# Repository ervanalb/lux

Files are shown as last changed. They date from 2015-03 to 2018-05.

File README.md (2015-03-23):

lux
===

Lux is a protocol for the transmission of power and data from a host device to one or more nodes. It is capable of data rates approaching 3 megabits per second and supplying 30 Watts of power over distances of up to 100 feet. It is designed to be easy to implement and uses low-cost cabling and connectors.

Lux was designed as a lighting control protocol, specifically for LED strips. But, it generalizes nicely to any sort of automation on a small to medium scale.

For tech-specs of the protocol, see SPECS.md.

In this repository, you will find:

Library
-------

The lux library is a architecture-independent implementation of the lux in C which you can use to implement your own lux nodes. Simply provide the necessary simple hardware abstraction layer, and you're good to go. The implementation fits in under 8K of program memory and 2K of RAM (1K of which is shared with the application) on a Cortex-M0.

LED strip firmware
------------------

This is a real-world instantiation of the lux protocol to control WS2811 or LPD6803 light strips. It uses a STM32F030 at 48 MHz, which has only 32K of FLASH and 4K of RAM for all of the processing. The code also implements a bootloader for firmware upgrades over lux.

Python
------

There is also a python implementation of a lux master using pyserial.

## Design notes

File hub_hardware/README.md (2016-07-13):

Lux Hub Hardware
================

History
-------

### Rev 6

#### Errata

- 

##### Bad parts

- U3
- R42
- C3 is short
- Fuse clips
- CON1 holes should be bigger

### Rev 5

- STM32F042
- 6 Lux outputs
    - 48V power, 5V/0V RS-422 data
    - Data lines tied together
    - Rx/Tx enable are indepedent
    - TVS on data lines
    - Per-output PTC fuses (which weren't useful)
- USB for comms & non-48V power
    - Spec'd for 500mA current draw to drive 6 ports
- *Greenwire*: 3v3 reg `U1` pads are incorrect
- *Greenwire*: Inrush limiter changed: `R42 -> C; C1 -> R; R1` unpopulated
- *Greenwire*: RX pin incorrect; shorted to TX LED

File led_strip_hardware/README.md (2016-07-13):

LED Strip Hardware
==================

Unified (v5, v6, v7)
------------

v7 Changelog
------------
- Doubled `C1` with `C10` (`+48V` filtering)
- Doubled `C9` with `C11` (`3V3` filtering)
- Added `C12`, 100nF decoupling cap to `U3`
- Improved DFM

v6 Changelog
------------
(Minor revision)
- Added soft-start circuit (`Q1`, `R9`, `R10`) to `+48V`
- Added bias resistors (`R11`, `R12`) to RS-422 lines
- Added transient voltage suppressor (`U5`) to RS-422 lines
- "*Greenwire*": Doubled `C1` (`+48V` filtering)
- "*Greenwire*": Doubled `C9` (`3V3` filtering)
- "*Greenwire*": Added 2x 100nF decoupling caps to `U3`

History
-------

### Rev 5-7

- 2015-2016
- STM32-based
- Comms: RS-422 half-duplex (actually works now)
    - Hub for multiplexing, but not a router
    - Network (UDP) bridge
- Power: 48V + buck
- Rendering: Control-side, full frames sent
- Control: Radiance: https://github.com/zbanks/radiance
    - Visual UI written in C & SDL
    - Effects on a 2D plane, rendered onto strips
    - Tight audio integration & visualization
        - Beat tracking: https://github.com/zbanks/BTrack

### Rev 3-4???

- 2014
- STM32-based
- Comms: RS-422 half-duplex
    - Non-simplex was incredibly unreliable
    - Full router prototyped, never worked
- Power: 48V + buck
- Rendering: Control-side, full frames sent
    - (Bespeckle used intermittently? Unclear)
- Control: Numerous revisions
    - Livecoding python: https://github.com/zbanks/beetle
        - Visual UI with grassroots: https://github.com/zbanks/grassroots
        - #doitlive: https://github.com/zbanks/doitlive
        - Effects projected on a 2D plane and rendered for strips
        - Used audio information (but not well), beats manually sync'd (?)
    - Beat-off: https://github.com/ervanalb/beat-off/tree/python-1d
        - Visual UI
        - 1D LED strips with effects composited
        - Audio info displayed, beats manually sync'd, effects use timing
- Repo: https://github.com/zbanks/aurora

### Rev 2

- Aug 2013
- STM32-based
- Comms: CAN
    - Bastardization of the protocol to get multicast
    - Possibly send-only?
- Power: 48V + buck
- Rendering: Bespeckle, rendering computed on-board
    - https://github.com/zbanks/bespeckle
- Control: Cursedlight, many-keyboards + TUI
    - https://github.com/zbanks/cursedlight
    - Audio manually sync'd
- Repo: https://github.com/ervanalb/canautomation

### Rev 1

- Aug 2012
- CPU: AVR("arduino compatible"!)
- Comms: MIDI
- Power: 12V DC jack
- Rendering: effects computed on board
    - Each MIDI note corresponded to effect + color
- Control: seq24 used for control
    - MIDI clock sync'd from Mixxx

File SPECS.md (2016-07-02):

Lux Specification
=================

Lux refers to a protocol stack which is designed to control many lightweight nodes. 

It supports the transmission of power and data from a host device to one or more nodes over a simple serial link. This mode is capable of data rates approaching 3 megabits per second and supplying 30 Watts of power over distances of up to 100 feet. It is designed to be easy to implement and uses low-cost cabling and connectors.

Additionally, it also supports transmitting data over UDP (e.g. with IP & Ethernet). This mode makes it easy to abstract the controller from the physical hardware.

### Stack Comparison

The *Serial/Hardware* stack is:

1. Serial Physical Layer (48V; RS-485; 3Mbps)
2. Data Link Layer (COBS; CRC)
3. MAC Layer (Speak-when-spoken-to)
4. Application Layer

The *Network/IP* stack is:

1. Physical Layer (Unspecified; e.g. Ethernet)
2. Data Link Layer (Unspecified; e.g. IPv4)
3. Transport Layer (UDP)
3. Data Link Layer (COBS; CRC)
3. MAC Layer (Speak-when-spoken-to)
4. Application Layer

Serial Physical Layer
---------------------

Lux is designed with a hub-and-spoke model in mind. Each lux universe must have exactly one master but may have an arbitrary number of nodes (limited only by the bandwidth of the bus.)

The master exposes one or more RJ-11 jacks (6p4c) and each node exposes one RJ-11 jack. Devices are connected with straight-through RJ-11 cables no longer than 100 feet and no thinner than 26 AWG per conductor.

The lux pinout is as follows:
 1. GND
 2. A
 3. B
 4. PWR

The voltage that nodes see between PWR and GND is nominally 48 volts, but may be as high as 54 volts or as low as 42 volts. The master or hub provides this power, and nodes consume it. The master should not output less than 48 volts or more than 54 volts. The drop in the cabling may be as large as 6 volts.

Nodes may be bus-powered or self-powered. A bus-powered node must not draw more than 650 mA from the bus. A self-powered node must use GND as reference for the data signals (i.e. must not be floating or at a different potential from the bus.)

RS-485 is used for the data lines. Nodes and masters should implement the recommended bias resistors and a termination resistor of 120 ohms, as well as a RS-485 compatible tranceiver capable of 3 megabit per second communcation. The serial protocol uses 3 megabaud, 8 data bits, 1 start bit, 1 stop bit, and no parity. The serial link is half-duplex.

Network Transport Layer
-----------------------

Lux uses UDP for sending data over the Internet/LAN. Lux does not specify which protocols must be used below UDP, but usualy it is IPv4 or IPv6.

Common Layers
-------------
### Data Link Layer
Lux packets are encoded using consistent-overhead byte stuffing (COBS). A NULL (out-of-band 0 byte) is placed at the end of a packet. 

Multi-byte values are transmitted in little-endian format (*not* "network"/big-endian!)

A packet consists of five parts:

<table><tr>
 <td>Destination Address <br> (4&nbsp;bytes)</td>
 <td>Command <br> (1&nbsp;byte)</td>
 <td>Index <br> (1&nbsp;byte)</td>
 <td width="100%">Payload <br> (0-1024&nbsp;bytes) </td>
 <td>CRC <br> (4&nbsp;bytes) </td>
</tr></table>

The destination address is four bytes. Nodes may have one or more addresses. One address may be used by multiple nodes (useful for multicast.) Because lux uses hubs, all traffic generated by the host will reach every node. Nodes should filter packets based on the address, and discard any packets not addressed to them. For the rest of this document, the address is assumed to be little-endian.

The *command* and *index* fields are one byte each. They are used by the application layer.

The payload can be between 0 and 1024 bytes long, inclusive (after COBS decoding.) The data contained in the payload is not specified by lux, except by way of the defacto standards described below. Packets with payloads longer than 1024 bytes should be discarded as corrupt.

After the payload comes a 32-bit CRC of the entire packet (after COBS decoding.) If the CRC does not check out, the packet should be discarded as corrupt.

Payload length is never explicitly stated. Instead, packets are null-teriminated. Payload length is defined as the packet length minus 8 bytes, to account for the address and checksum.

Packets shorter than 8 bytes should be discarded, though not necessarily marked as corrupt. An optional feature of this protocol is to start (as well as end) packets with a null. When this happens, the decoder may interpret the data between packets as packets. On an ideal busimplementing this two-zero variant, these packets are of length 0 and do not indicate an error condition.

### MAC Layer

Lux uses a speak-when-spoken-to access control scheme. The master sends packets out to the nodes, and may optionally expect a response. If the master expects a response and does not receive one, it may re-send the packet after a timeout mutually agreed upon in advance by the node and the master. Nodes can only send data back to the master. Node should never spuriously send packets, as they may collide with packets originating from the master.

Due to the topology of the bus, packets originating from nodes will not necessarily reach other nodes. Nodes that are sending packets to the master should clear the destination field (set it to all zeros.) Nodes should never react to packets with this address.

### Application Layer

Each packet sent to a node is a *command*. Commands should be as idempotent/stateless as possible.

The command byte (octet 5) indicates the command type. `0x00` through `0x1F` are reserved for commands common to all lux devices, `0x20` through `0xFF` are device-specific. Example commands inclue ``GET_ID``, ``RESET``, ``GET_ADDR``, ``SET_ADDR``, ``GET_PKTCNT``, ``RESET_PKTCNT``, etc. 

<!-- Some command IDs are common to all lux nodes, others are specific to particular node types. For example, ``FRAME`` is specific to LED strips. -->

#### Responses

In keeping with the MAC, nodes can only transmit responses -- they cannot "push" data. Some commands are *send-recieve*, and are defined to require a response. Others like ``RESET`` are *send-only* do not have a response. It is a violiation of the MAC to respond to send-only command, or to respond with zero or multiple packets to a send-recieve command.

In a response, the destination is set to `0x00000000`, and the `command` and `index` fields are copied from the request packet.

A commmon response is a simple *ACK* containing no other data. In this case, the first byte of the payload is set to `0x00`, followed by the CRC from the request packet. Alternatively, in the case of an error (*NAK*), the response consists of a non-zero error code, followed by the CRC of the request packet (as in an *ACK*).

#### Command Descriptions

Name            | Resp.     | Payload           | Description 
----------------|-----------|-------------------|-------------
`RESET`         | None      | `flags`, 1 byte   | Reboot/reset the node. `flags` are implementation-specific.
`GET_ID`        | Data      | None              | Respond with string containing node name. Identifies implementation running on node.
`GET_DESCRIPTOR`| Data      | None              | Respond with JSON blob describing node.
`GET_ADDR`      | Data      | None              | 72 byte address struct, each `u32`: `{mcast_addr, mcast_mask, unicast_addrs[16]}`
`SET_ADDR`      | Ack       | `addrs`, 72 bytes | Respond with address list, see `GET_ADDR`
`WRITE_CONFIG`  | Ack       | None              | Flush configuration changes to nonvolatile storage
`GET_PKTCNT`    | Data      | None              | Respond with 20 byte counter struct, each `u32`: `{good, malformed, overrun, bad_crc, rx_interrupted}`
`RESET_PKTCNT`  | Ack       | None              | Reset all packet counters to 0

#### `index`

In some cases, it is desirable for a command to transmit more than 1024 bytes. The `index` parameter allows bulk transfers (up to 256kB) by selecting a slice of a request/response.

If a command requires multiple packets, it is important to note that there is no "transaction" -- the node is not required to maintain state. As a result a node does not need to keep track of which segements it has sent or received.

De-facto standards
------------------

The following are not mandatory for implementing a correctly-functioning lux node. However, they are highly recommended to maintain compatibility between nodes.

Nodes should always accept packets on address 0xFFFFFFFF. That way, a node with an unknown or corrupt address filter can always be reached.

Uninitialized nodes should assume address 0x80000000. That way, the master can "enumerate" new nodes by continuously sending zero-length packets to 0x80000000. When an unitialized node is found, it should be configured with a permanent address and stop listening on 0x80000000.

Lux Devices
===========

LED Strip
---------

### Description

A collection of up to 65535 RGB pixels. Each pixel can be controlled independently, with 24 bits of color depth.

### Command Descriptions

In addition to the generic lux commands:

Name            | Resp.     | Payload               | Description 
----------------|-----------|-----------------------|-------------
`FRAME`         | None      | `frame`, *3n* bytes   | Display the payload
`FRAME_ACK`     | Ack       | `frame`, *3n* bytes   | See `FRAME`, but ack
`FRAME_HOLD`    | None      | `frame`, *3n* bytes   | Buffer the payload as a frame, but don't display it
`FRAME_HOLD_ACK`| Ack       | `frame`, *3n* bytes   | See `FRAME_HOLD`, but ack
`SYNC`          | None      | None                  | Display the buffered frame from `FRAME_HOLD` or `FRAME_HOLD_ACK`
`SYNC_ACK`      | Ack       | None                  | See `SYNC`, but ack
`SET_LED`       | Ack       | None                  | Turn the on-board LED on or off
`GET_BUTTON_CNT`| Data      | None                  | Respond with number of times the button has been pressed
`SET_LENGTH`    | Ack       | None                  | Set the number of pixels
`GET_LENGTH`    | Data      | None                  | (*To be deprecated*) Respond with number of pixels

`frame` buffers must be exactly *3n* bytes long, where *n* is the length of the strip as discovered by `GET_DESCRIPTOR` or `GET_LENGTH`.
The three consecutive bytes represent `R`, `G`, and `B` components respectively. 

LED Spot
--------

### Description

A single RGB pixel with 24 bits of color depth

### Command Descriptions

In addition to the generic lux commands:

Name            | Resp.     | Payload               | Description 
----------------|-----------|-----------------------|-------------
`FRAME`         | None      | `frame`, 3 bytes      | Display the payload
`FRAME_ACK`     | Ack       | `frame`, 3 bytes      | See `FRAME`, but ack
`FRAME_HOLD`    | None      | `frame`, 3 bytes      | Buffer the payload, but don't display it
`FRAME_HOLD_ACK`| Ack       | `frame`, 3 bytes      | See `FRAME_HOLD`, but ack
`SYNC`          | None      | None                  | Display the buffered color from `FRAME_HOLD` or `FRAME_HOLD_ACK`
`SYNC_ACK`      | Ack       | None                  | See `SYNC`, but ack
`SET_LED`       | Ack       | None                  | Turn the on-board LED on or off

Bootloader
----------

### Description

A bootloader implementation for re-flashing devices in the field.

### Command Descriptions

In addition to the generic lux commands:

Name            | Resp.     | Payload               | Description 
----------------|-----------|-----------------------|-------------
`INVALIDATE_APP`| Ack       | None                  | Prevent the existing application from booting
`FLASH_ERASE`   | Ack       | `u32 addr` page       | Erase a FLASH page at base address `addr`
`FLASH_WRITE`   | Data      | `u32 addr, data[]`    | Write `data` to FLASH at address `addr`. Respond with data written.
`FLASH_READ`    | Data      | `u32 addr, u16 len`   | Read back `len` bytes of data from `addr`

It is important to call `INVALIDATE_APP` before writing to FLASH.
This "atomically" re-writes the ISR page to point to the bootlodaer, which causes subsequent reboots to jump to the bootloader instead of the application until the flashing is done.

The flashing process should go as follows: 

```
    > INVALIDATE_APP
    < Ack
    > FLASH_ERASE 0x800
    < Ack
    > FLASH_WRITE 0x800 deadbeef...
    < deadbeef...
    > FLASH_WRITE 0x900 deadbeef...
    < deadbeef...
    > FLASH_ERASE 0x400
    < Ack
    ...
    > FLASH_WRITE 0x000 deadbeef...
    < deadbeef...
    > RESET
```

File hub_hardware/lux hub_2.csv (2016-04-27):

100n | 2 | C5 C6
1u | 1 | C2
2u2 | 1 | C4
470u | 1 | C3
C | 1 | C1
C | 6 | C7 C8 C9 C10 C11 C12
48V | 1 | CON1
USB-MINI-B | 1 | CON2
TX | 1 | D1
RX | 1 | D2
ENABLED | 6 | D3 D5 D7 D9 D11 D13
PWR | 6 | D4 D6 D8 D10 D12 D14
VDD | 1 | D15
+48V | 1 | D16
5A | 1 | F1
CONN_4 | 7 | P1 P2 P3 P4 P5 P6 P7
DMP6023LE-13 | 1 | Q1
120R | 6 | R8 R14 R20 R26 R32 R38
470R | 9 | R4 R5 R6 R12 R18 R24 R30 R36 R50
680R | 12 | R7 R13 R19 R25 R31 R37 R9 R15 R21 R27 R33 R39
2K2 | 6 | R11 R17 R23 R29 R35 R41
4K7 | 1 | R2
10K | 7 | R3 R43 R44 R45 R46 R47 R48
10k | 1 | R49
R | 2 | R1 R42
PTC | 6 | R10 R16 R22 R28 R34 R40
BOOT | 1 | SW1
4068 | 1 | U3
3V3REG | 1 | U1
ISL83485IBZ | 6 | U4 U6 U8 U10 U12 U14
2CH-TVS | 6 | U5 U7 U9 U11 U13 U15
STM32F042-32 | 1 | U2

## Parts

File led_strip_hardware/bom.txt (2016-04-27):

C1:C3225X7R2A225K230AB
C6:16SVPF82M
C7:16SVPF82M
D2:STPS20M100S
P1:A-2004-0-4-LP-N-R
SW1:FSM4JSMA
U1:ISL83485IBZ
U3:STM32F030K6T6
U4:AP1117IE33G-13

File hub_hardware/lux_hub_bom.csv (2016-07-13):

Digi-Key Part Number | Manufacturer | Manufacturer Part Number | Customer Reference | Quantity 1 | Quantity 2 | Quantity 3 | Mfg Std Lead Time | Description | Comments | RoHS Status | Lead Free Status | REACH Status
490-10458-1-ND | MURATA ELECTRONICS (VA) | GRM155R62A104KE14D | C1,C13 | 2 | 0 | 0 | 16 Weeks | CAP CER 0.1UF 100V X5R 0402 | Alternate Packaging Exists | RoHS Compliant | Lead free | Unaffected Dec-2015
490-13341-1-ND | MURATA ELECTRONICS (VA) | GRM155R71E104ME14D | C5,C6,C7,C8,C9,C10,C11,C12,C13,C14 | 10 | 0 | 0 | 18 Weeks | CAP CER 0.1UF 25V X7R 0402 | Alternate Packaging Exists | RoHS Compliant | Lead free | Unaffected Dec-2015
1276-1066-1-ND | SAMSUNG ELECTRO-MECHANICS AMERICA, INC (VA) | CL21B105KAFNNNE | C2 | 1 | 0 | 0 | 10 Weeks | CAP CER 1UF 25V X7R 0805 | Alternate Packaging Exists | RoHS Compliant | Lead free | Unaffected Dec-2015
1276-2953-1-ND | SAMSUNG ELECTRO-MECHANICS AMERICA, INC (VA) | CL21B225KAFNFNE | C4 | 1 | 0 | 0 | 10 Weeks | CAP CER 2.2UF 25V X7R 0805 | Alternate Packaging Exists | RoHS Compliant | Lead free | Unaffected Dec-2015
1276-6462-1-ND | SAMSUNG ELECTRO-MECHANICS AMERICA, INC (VA) | CL21A475KAQNNNG | C15 | 1 | 0 | 0 | 10 Weeks | CAP CER 4.7UF 25V X5R 0805 | Alternate Packaging Exists | RoHS Compliant | Lead free | Not Available
160-1435-1-ND | LITE-ON INC (VA) | LTST-C190KGKT | D1,D3,D5,D7,D9,D11,D13,D15 | 8 | 0 | 0 | 10 Weeks | LED GREEN CLEAR 0603 SMD | Alternate Packaging Exists | RoHS Compliant | Lead free | Unaffected Dec-2015
160-1436-1-ND | LITE-ON INC (VA) | LTST-C190KRKT | D2,D4,D6,D8,D10,D12,D14,D16 | 8 | 0 | 0 | 10 Weeks | LED RED CLEAR 0603 SMD | Alternate Packaging Exists | RoHS Compliant | Lead free | Unaffected Dec-2015
AE10382-ND | ASSMANN WSW COMPONENTS | A-2004-0-4-LP-N-R | P1,P2,P3,P4,P5,P6 | 6 | 0 | 0 | 16 Weeks | CONN MOD JACK 6P4C R/A UNSHLD |  | RoHS Compliant | Lead free | Unaffected Dec-2015
DMP6023LE-13DICT-ND | DIODES INCORPORATED (VA) | DMP6023LE-13 | Q1 | 1 | 0 | 0 | 6 Weeks | MOSFET P-CH 60V 7A SOT223 | Alternate Packaging Exists | RoHS Compliant | Lead free | Unaffected Dec-2015
P13593SCT-ND | PANASONIC ELECTRONIC COMPONENTS (VA) | EVQ-PE104K | SW1 | 1 | 0 | 0 | 6 Weeks | SWITCH TACTILE SPST-NO 0.05A 12V | Alternate Packaging Exists | RoHS Compliant | Lead free | Unaffected Jun-2015
497-14648-ND | STMICROELECTRONICS | STM32F042C6T6 | U2 | 1 | 0 | 0 | 11 Weeks | IC MCU 32BIT 32KB FLASH 48LQFP |  | RoHS Compliant | Lead free | Unaffected Jun-2015
296-14521-1-ND | TEXAS INSTRUMENTS (VA) | CD74HC30M96 | U3 | 1 | 0 | 0 | 6 Weeks | IC GATE NAND 1CH 8-INP 14-SOIC | Alternate Packaging Exists | RoHS Compliant | Lead free | Unaffected Dec-2015
DT1452-02SO-7DICT-ND | DIODES INCORPORATED (VA) | DT1452-02SO-7 | U5,U7,U9,U11,U13,U15 | 6 | 0 | 0 | 6 Weeks | TVS DIODE 5.5VWM 11VC SOT23 | Alternate Packaging Exists | RoHS Compliant | Lead free | Unaffected Dec-2015
ISL83485IBZ-TCT-ND | INTERSIL (VA) | ISL83485IBZ-T | U4,U6,U8,U10,U12,U14 | 6 | 0 | 0 | 6 Weeks | IC TXRX RS485/422 3.3V LP 8SOIC | Alternate Packaging Exists | RoHS Compliant | Lead free | Unaffected Dec-2015
311-680HRCT-ND | YAGEO (VA) | RC0603FR-07680RL | R7,R9,R13,R15,R19,R21,R25,R27,R31,R33,R37,R39 | 12 | 0 | 0 | 22 Weeks | RES SMD 680 OHM 1% 1/10W 0603 | Alternate Packaging Exists | RoHS Compliant | Lead free | Unaffected Dec-2015
311-120HRCT-ND | YAGEO (VA) | RC0603FR-07120RL | R8,R14,R20,R26,R32,R38 | 6 | 0 | 0 | 22 Weeks | RES SMD 120 OHM 1% 1/10W 0603 | Alternate Packaging Exists | RoHS Compliant | Lead free | Unaffected Dec-2015
311-10KGRCT-ND | YAGEO (VA) | RC0603JR-0710KL | R3,R11,R17,R23,R29,R35,R41,R50 | 8 | 0 | 0 | 22 Weeks | RES SMD 10K OHM 5% 1/10W 0603 | Alternate Packaging Exists | RoHS Compliant | Lead free | Unaffected Dec-2015
311-15KGRCT-ND | YAGEO (VA) | RC0603JR-0715KL | R2 | 1 | 0 | 0 | 22 Weeks | RES SMD 15K OHM 5% 1/10W 0603 | Alternate Packaging Exists | RoHS Compliant | Lead free | Unaffected Dec-2015
311-100KJRCT-ND | YAGEO (VA) | RC0402JR-07100KL | R1 | 1 | 0 | 0 | 22 Weeks | RES SMD 100K OHM 5% 1/16W 0402 |  | RoHS Compliant | Lead free | Unaffected Dec-2015
311-470JRCT-ND | YAGEO (VA) | RC0402JR-07470RL | R4,R5,R6,R12,R18,R24,R30,R36,R49 | 9 | 0 | 0 | 22 Weeks | RES SMD 470 OHM 5% 1/16W 0402 | Alternate Packaging Exists | RoHS Compliant | Lead free | Unaffected Dec-2015
YAG1281CT-ND | YAGEO (VA) | RC0402JR-0710KP | R43,R44,R45,R46,R47,R48 | 6 | 0 | 0 | 22 Weeks | RES SMD 10K OHM 5% 1/16W 0402 | Alternate Packaging Exists | RoHS Compliant | Lead free | Unaffected Dec-2015
151-1206-1-ND | EDAC INC (VA) | 690-005-299-043 | CON2 | 1 | 0 | 0 | 15 Weeks | CONN MINI USB RCPT RA TYPE B SMD | Alternate Packaging Exists | RoHS Compliant | Lead free | Unaffected Jun-2015

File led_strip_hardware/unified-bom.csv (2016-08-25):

Identifier | Digikey
C2 | 490-6328-1-ND
C8 | 490-6328-1-ND
C9 | 1276-6459-1-ND
C11 | 1276-6459-1-ND
C12 | 490-6328-1-ND
D1 | 732-4981-1-ND
D3 | 1SMB58AT3GOSCT-ND
Q1 | CPH3351-TL-WOSCT-ND
R1 | 311-120HRCT-ND
R4 | 311-220JRCT-ND
R7 | 311-1.0KJRCT-ND
R8 | 311-1.0KJRCT-ND
R9 | 311-22KJRCT-ND
R10 | 311-47KJRCT-ND
R11 | 311-680HRCT-ND
R12 | 311-680HRCT-ND
SW1 | EG4621CT-ND
U1 | ISL83485IBZ-TCT-ND
U3 | 497-14046-ND
U5 | 296-40695-6-ND
C1 | 445-6043-1-ND
C3 | 490-6328-1-ND
C4 | 490-6353-1-ND
C5 | 490-5868-1-ND
C6 | P16482CT-ND
C7 | P16482CT-ND
C10 | 445-6043-1-ND
D2 | 497-10993-1-ND
L1 | XAL6060-103MEB
R2 | 311-270KJRCT-ND
R3 | 311-27JRCT-ND
R5 | RC0402FR-0768KL
R6 | RC0402FR-0712KL
U2 | 296-36527-1-ND
U4 | NCP1117LPST33T3GOSCT-ND

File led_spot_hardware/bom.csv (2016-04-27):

OPL SKU | Qty. | Parts
302010138 | 2 | C2 C9
302010139 | 3 | C5 C6 C7
304090044 | 1 | D4
301010251 | 2 | R7 R11
301010132 | 3 | R1 R10 R12
301010084 | 1 | R2
301010260 | 2 | R3 R5
301010194 | 1 | R4
301010315 | 1 | R6

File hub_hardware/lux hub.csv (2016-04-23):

OPL SKU | Qty. | Parts
304090046 | 8 | D4,D6,D8,D10,D12,D14,D15,D16
301010088 | 9 | R4,R5,R6,R12,R18,R24,R30,R36,R50
301010260 | 12 | R7,R13,R19,R25,R31,R37,R9,R15,R21,R27,R33,R39
301010254 | 7 | R2,R11,R17,R23,R29,R35,R41
301010288 | 7 | R3,R43,R44,R45,R46,R47,R48,R49
301010194 | 6 | R8 R14 R20 R26 R32 R38
302010138 | 8 | C5,C6,C7,C8,C9,C10,C11,C12
320010013 | 1 | CON2
304090039 | 1 | D1
304090057 | 7 | D2,D3,D5,D7,D9,D11,D13

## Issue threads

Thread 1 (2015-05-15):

LUX hub transceivers burn out

ervanalb, 2015-05-15:
Most likely due to 48 volts applied to data lines

ervanalb, 2015-09-21:
Appears to be fixed in rev6, still need to do stress testing

Closed 2018-06-13.

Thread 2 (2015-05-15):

RX babble

ervanalb, 2015-05-15:
Fix: add biasing resistors

ervanalb, 2015-09-21:
fixed in rev6

Closed 2015-09-21.

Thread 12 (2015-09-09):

Resistors for LEDs on 48V draw too much power

ervanalb, 2015-09-09:
(46 volts)^2 / 2200 ohms = 1 watt

ervanalb, 2015-09-09:
Suggested fix: upsize to 10K 1206

though we may just want to put a buck converter on the board

ervanalb, 2015-09-20:
R2 as well

Closed 2018-06-13.

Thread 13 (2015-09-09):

Resistors for LEDs don't light LEDs brightly enough

ervanalb, 2015-09-09:
Suggested fix: change to 330 ohms

ervanalb, 2015-09-21:
actually 470 ohms is fine

Closed 2015-09-21.

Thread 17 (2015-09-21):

C6, C7 have wrong value on schematic

ervanalb, 2015-09-21:
should be 82uF

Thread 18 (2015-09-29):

Shorting 48V to data lines fries all silicon on hub

ervanalb, 2015-09-29:
Presumably also all silicon on a connected LED board.

Does not appear to propagate through hub board into other LED boards.

zbanks, 2018-06-13:
Is this fixed now?

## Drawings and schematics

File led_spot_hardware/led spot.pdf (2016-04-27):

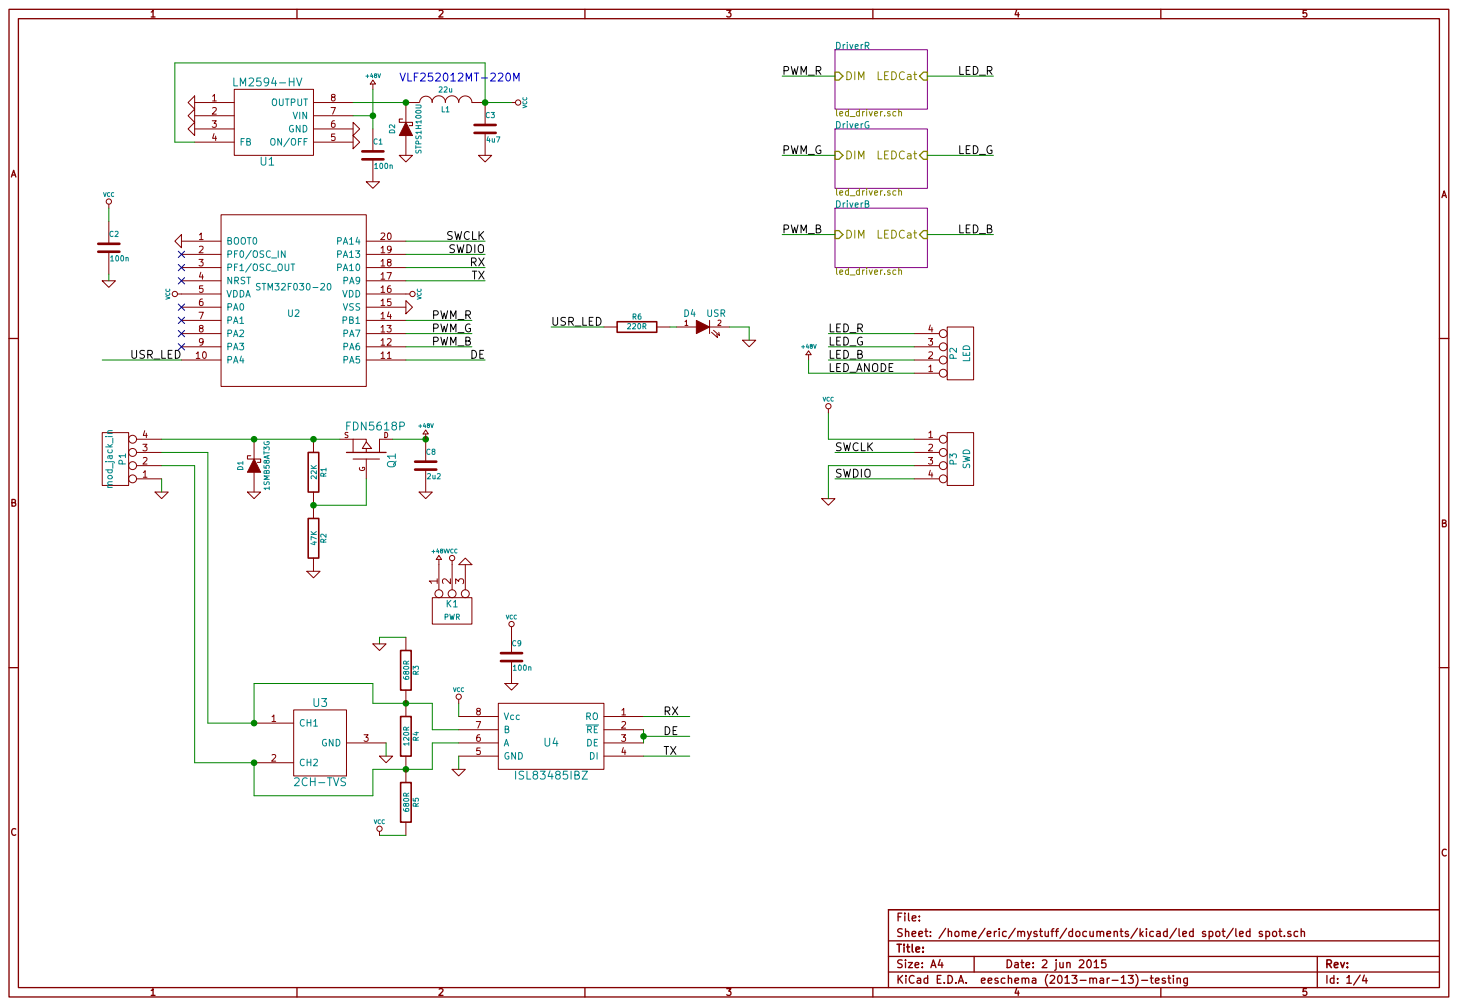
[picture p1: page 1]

C Sheet: /home/eric/mystuff/documents/kicad/led spot/led spot.sch File: Title:

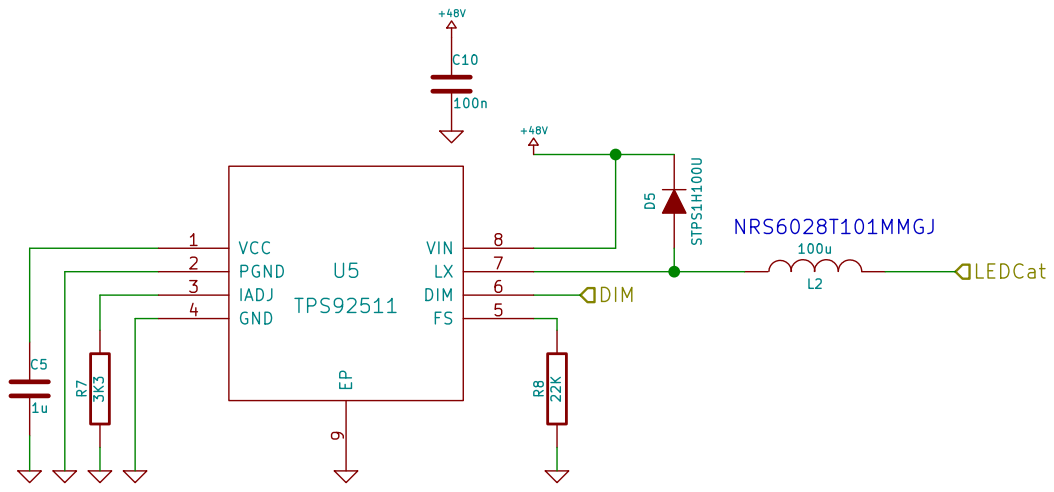
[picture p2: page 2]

C Sheet: led_driver.sch File: Title:

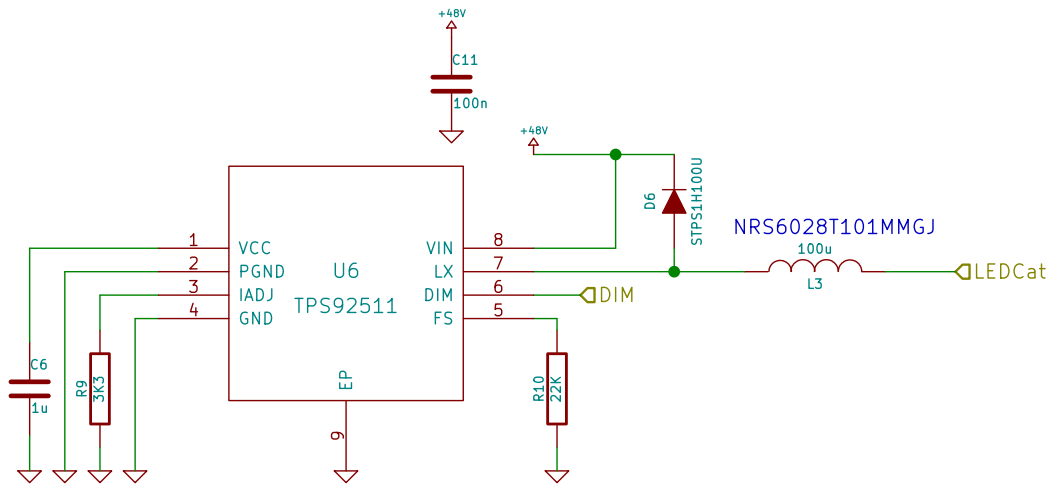
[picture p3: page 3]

C Sheet: led_driver.sch File: Title:

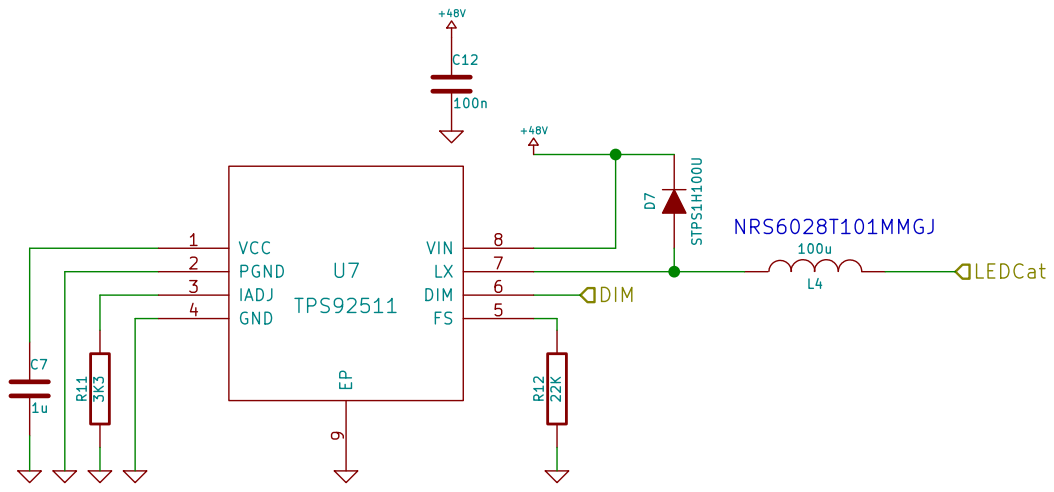
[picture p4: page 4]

C Sheet: led_driver.sch File: Title:

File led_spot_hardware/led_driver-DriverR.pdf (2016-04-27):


C Sheet: led_driver.sch File: Title:

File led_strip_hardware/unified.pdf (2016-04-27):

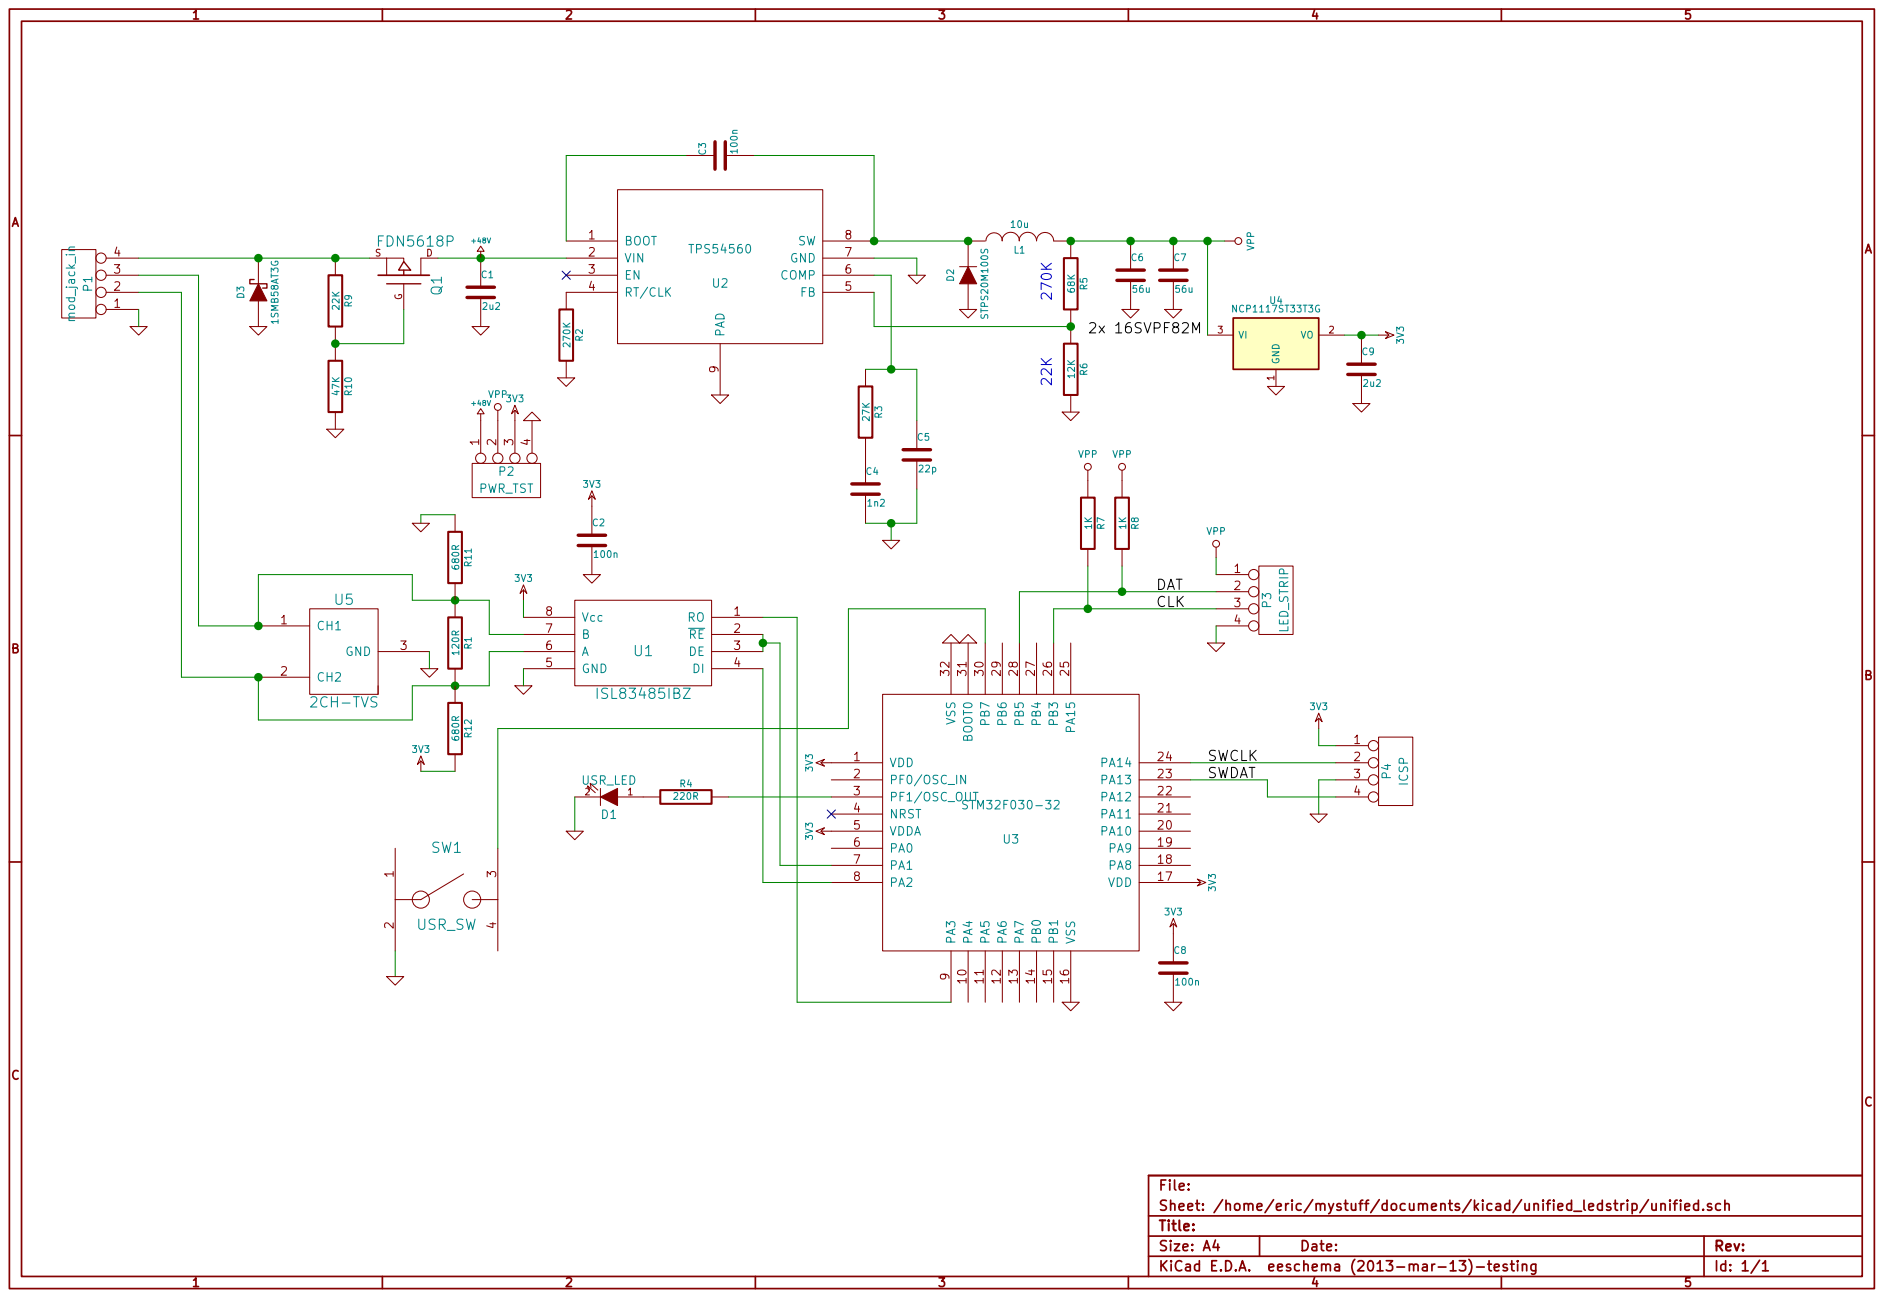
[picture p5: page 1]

C Sheet: /home/eric/mystuff/documents/kicad/unified_ledstrip/unified.sch File: Title:

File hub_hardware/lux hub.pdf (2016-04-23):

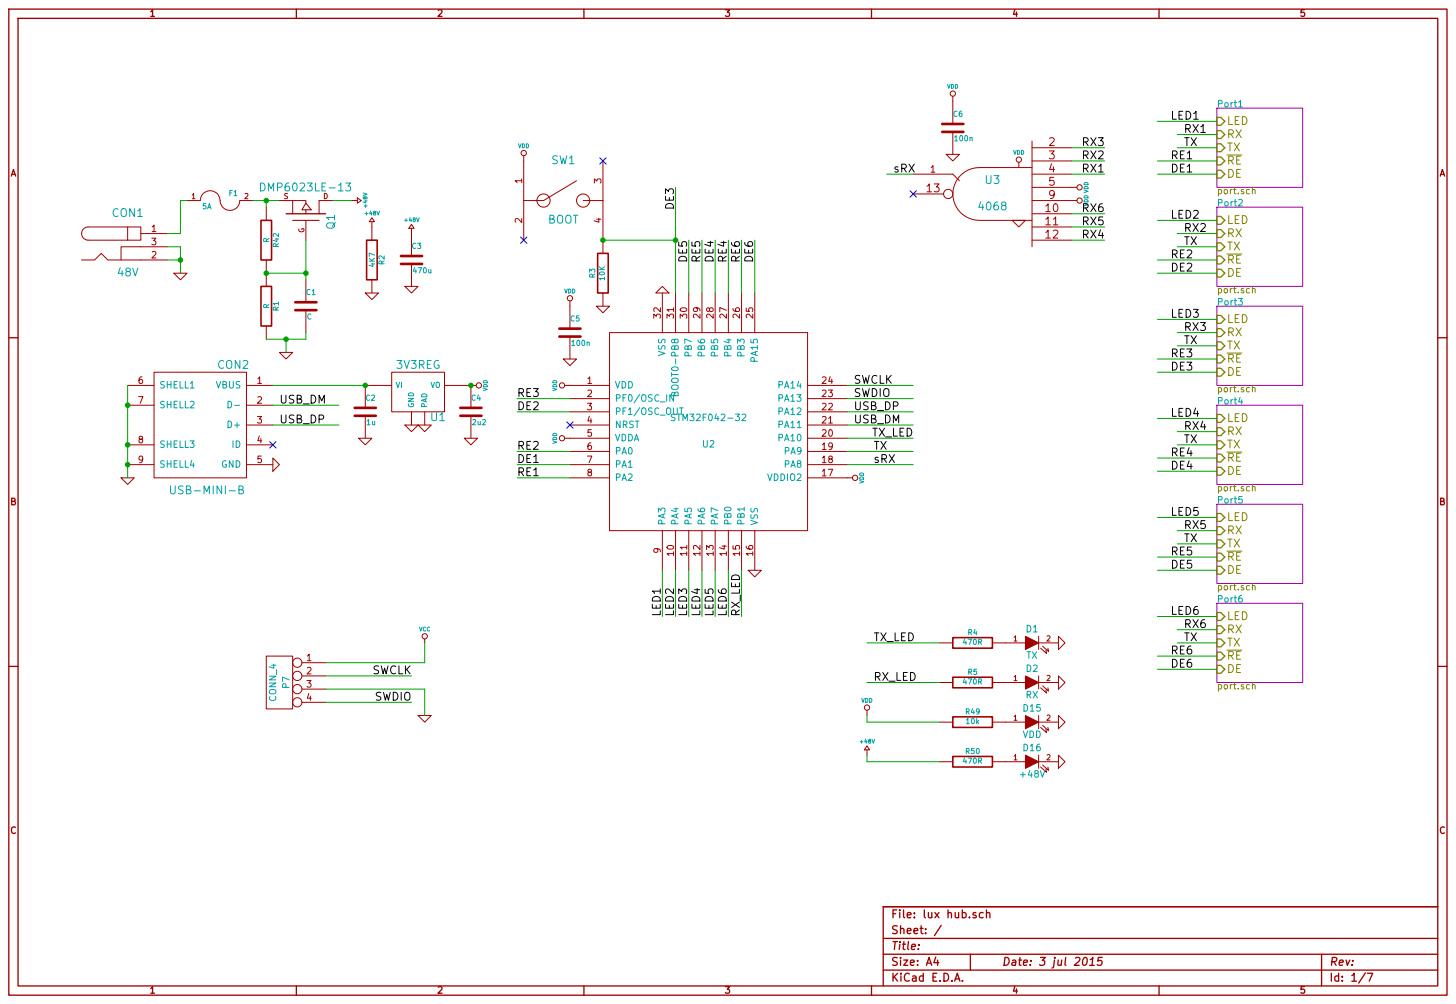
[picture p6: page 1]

Id: 1/7 Title: File: lux hub.sch Sheet: /

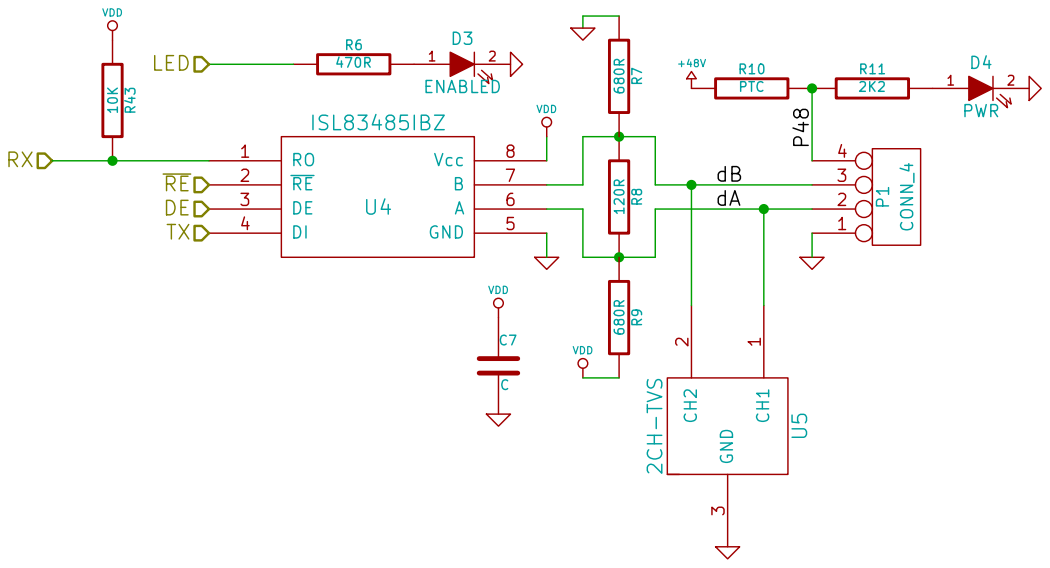
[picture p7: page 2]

Id: 2/7 Title: noname.sch File: port.sch
Sheet: /Port1/

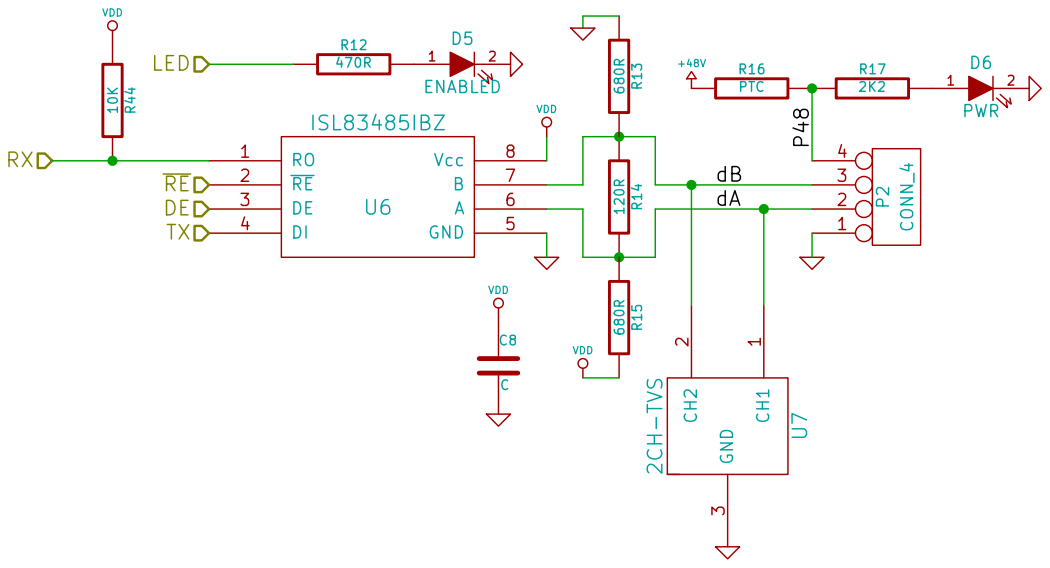
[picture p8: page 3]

Id: 3/7 Title: noname.sch File: port.sch
Sheet: /Port2/

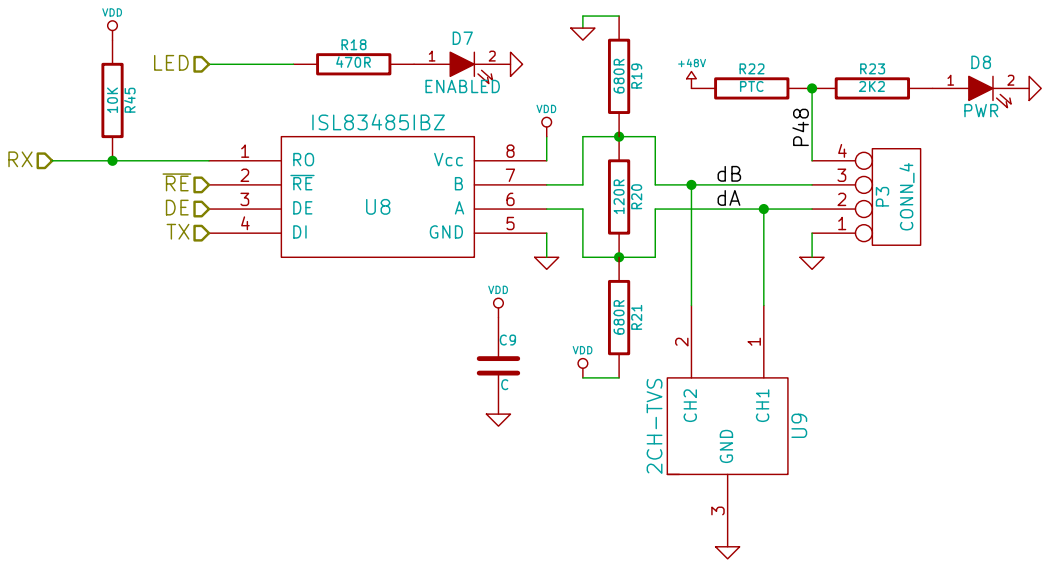
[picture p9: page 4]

Id: 4/7 Title: noname.sch File: port.sch
Sheet: /Port3/

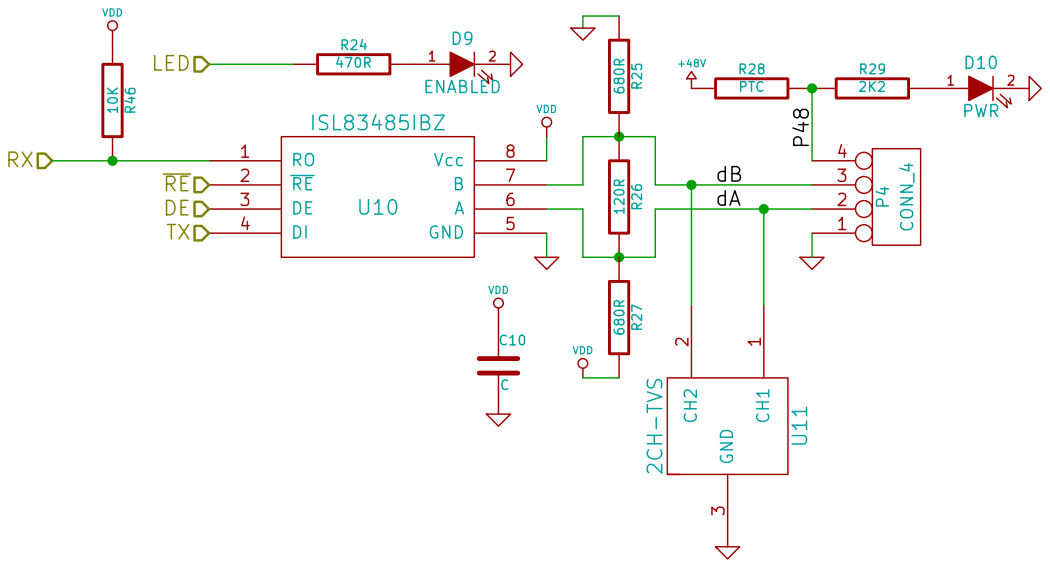
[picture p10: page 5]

Id: 5/7 Title: noname.sch File: port.sch
Sheet: /Port4/

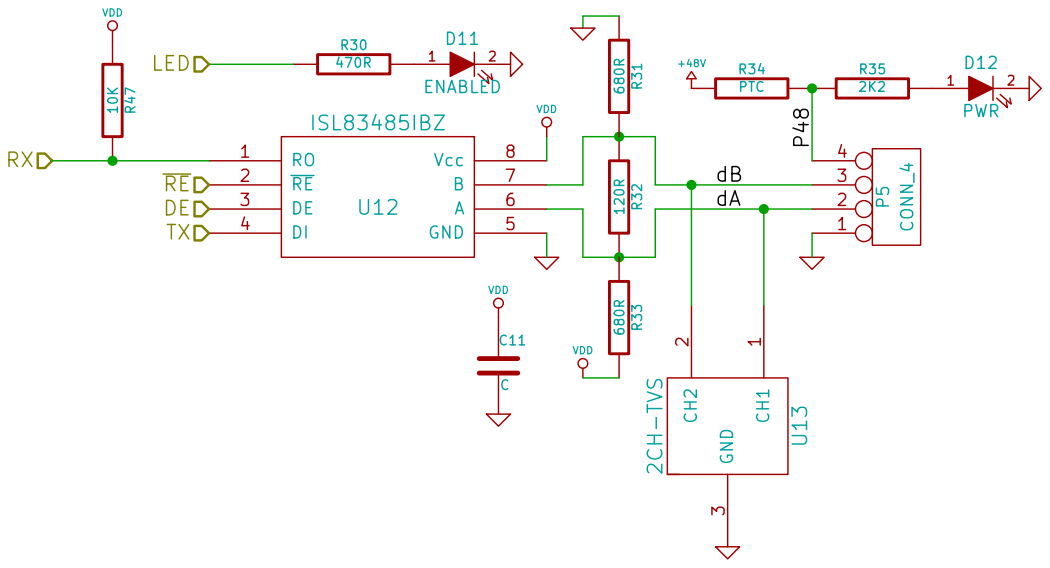
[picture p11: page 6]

Id: 6/7 Title: noname.sch File: port.sch
Sheet: /Port5/

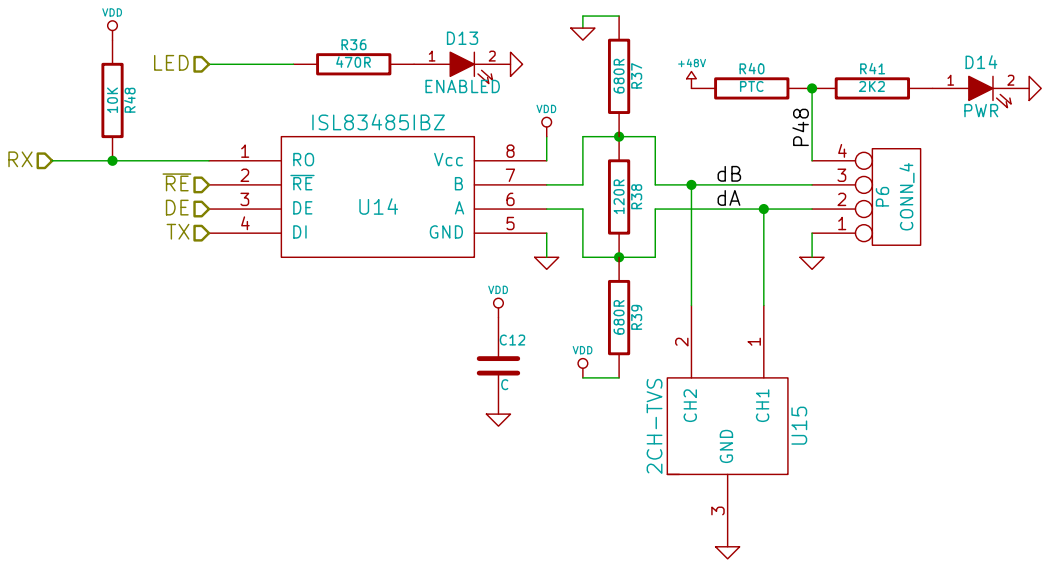
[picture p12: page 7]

Id: 7/7 Title: noname.sch File: port.sch
Sheet: /Port6/

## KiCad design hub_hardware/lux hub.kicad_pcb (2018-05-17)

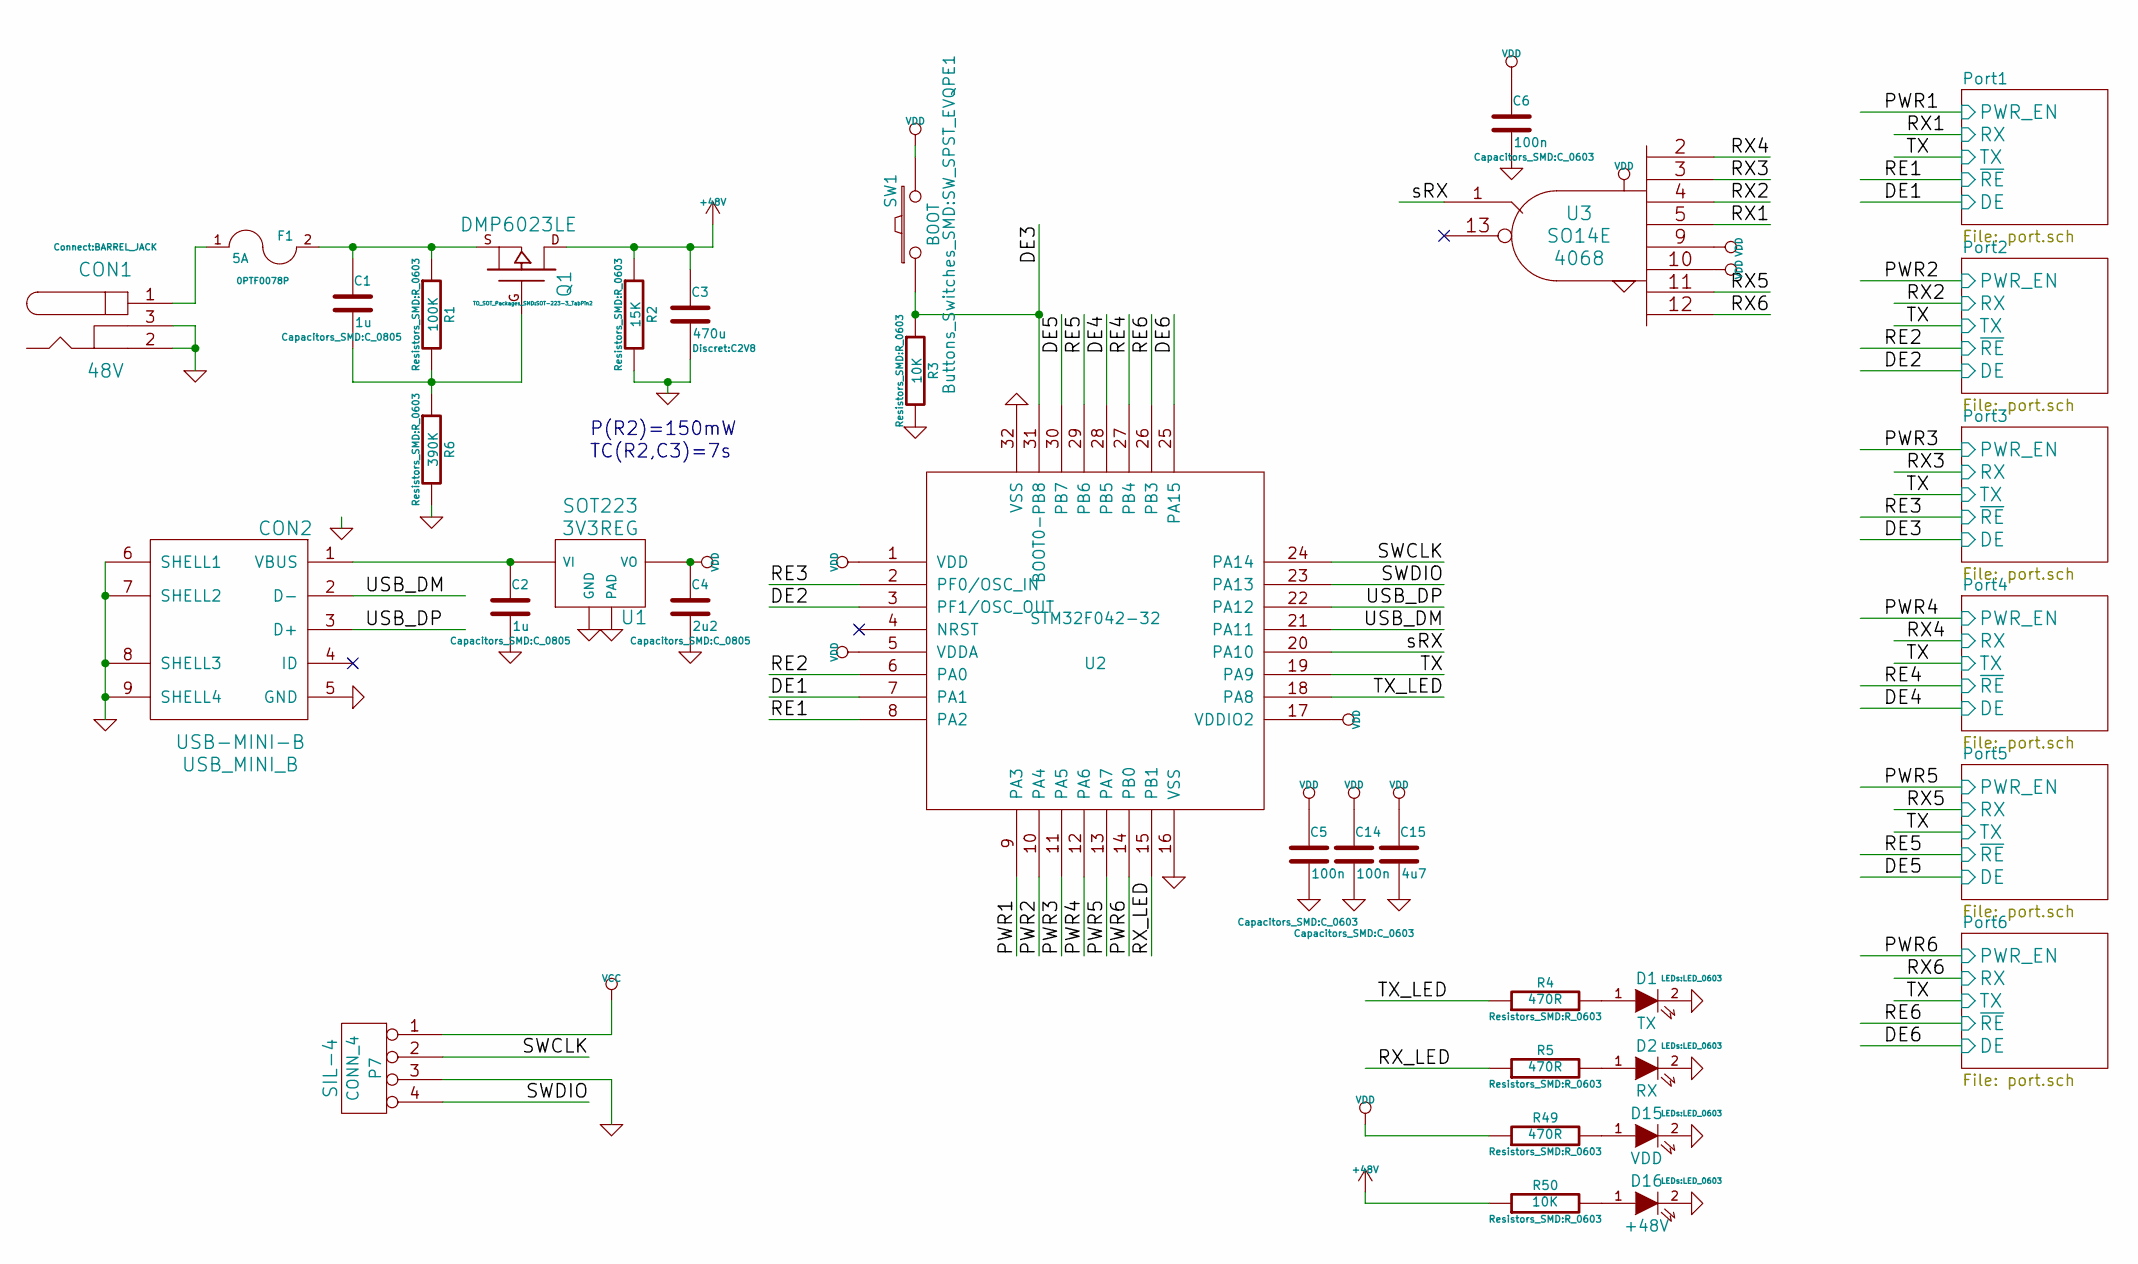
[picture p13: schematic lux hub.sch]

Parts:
C1, C2: 1u; C_0805
C3: 470u; C2V8
C4: 2u2; C_0805
C5, C6, C14: 100n; C_0603
C15: 4u7; C_0805
CON1: 48V; BARREL_JACK
CON2: USB-MINI-B; USB_MINI_B
D1: TX; LED_0603
D2: RX; LED_0603
D15: VDD; LED_0603
D16: +48V; LED_0603
F1: 5A; 0PTF0078P
P7: CONN_4; SIL-4
Q1: DMP6023LE; SOT-223-3_TabPin2
R1: 100K; R_0603
R2: 15K; R_0603
R3, R50: 10K; R_0603
R4, R5, R49: 470R; R_0603
R6: 390K; R_0603
SW1: BOOT; SW_SPST_EVQPE1
U1: 3V3REG; SOT223
U2: STM32F042-32; LQFP32
U3: 4068; SO14E

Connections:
+48V: C3.1, Q1.D, R2.1, R50.1; also elsewhere on the board
/DE1: U2.7 (PA1); also elsewhere on the board
/DE2: U2.3 (PF1/OSC_OUT); also elsewhere on the board
/DE3: R3.1, SW1.1, U2.31 (BOOT0-PB8); also elsewhere on the board
/DE4: U2.28 (PB5); also elsewhere on the board
/DE5: U2.30 (PB7); also elsewhere on the board
/DE6: U2.25 (PA15); also elsewhere on the board
/PWR1: U2.9 (PA3); also elsewhere on the board
/PWR2: U2.10 (PA4); also elsewhere on the board
/PWR3: U2.11 (PA5); also elsewhere on the board
/PWR4: U2.12 (PA6); also elsewhere on the board
/PWR5: U2.13 (PA7); also elsewhere on the board
/PWR6: U2.14 (PB0); also elsewhere on the board
/RE1: U2.8 (PA2); also elsewhere on the board
/RE2: U2.6 (PA0); also elsewhere on the board
/RE3: U2.2 (PF0/OSC_IN); also elsewhere on the board
/RE4: U2.27 (PB4); also elsewhere on the board
/RE5: U2.29 (PB6); also elsewhere on the board
/RE6: U2.26 (PB3); also elsewhere on the board
/RX1: U3.5; also elsewhere on the board
/RX2: U3.4; also elsewhere on the board
/RX3: U3.3; also elsewhere on the board
/RX4: U3.2; also elsewhere on the board
/RX5: U3.11; also elsewhere on the board
/RX6: U3.12; also elsewhere on the board
/RX_LED: R5.1, U2.15 (PB1)
/SWCLK: P7.2, U2.24 (PA14)
/SWDIO: P7.4, U2.23 (PA13)
/TX: U2.19 (PA9); also elsewhere on the board
/TX_LED: R4.1, U2.18 (PA8)
/USB_DM: CON2.2 (D-), U2.21 (PA11)
/USB_DP: CON2.3 (D+), U2.22 (PA12)
/sRX: U2.20 (PA10), U3.1
GND: C2.2, C3.2, C4.2, C5.2, C6.2, C14.2, C15.2, CON1.2, CON1.3, CON2.5 (GND), CON2.6 (SHELL1), CON2.7 (SHELL2), CON2.8 (SHELL3), CON2.9 (SHELL4), D1.2 (K), D2.2 (K), D15.2 (K), D16.2 (K), P7.3, R2.2, R3.2, R6.2, U1.2 (GND), U1.4 (PAD), U2.16 (VSS), U2.32 (VSS), U3.7 (GND); also elsewhere on the board
unnamed: C1.1, F1.2, Q1.S, R1.1
unnamed: C1.2, Q1.G, R1.2, R6.1
unnamed: C2.1, CON2.1 (VBUS), U1.1 (VI)
unnamed: CON1.1, F1.1
unnamed: D1.1 (A), R4.2
unnamed: D2.1 (A), R5.2
unnamed: D15.1 (A), R49.2
unnamed: D16.1 (A), R50.2

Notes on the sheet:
P(R2)=150mW
TC(R2,C3)=7s

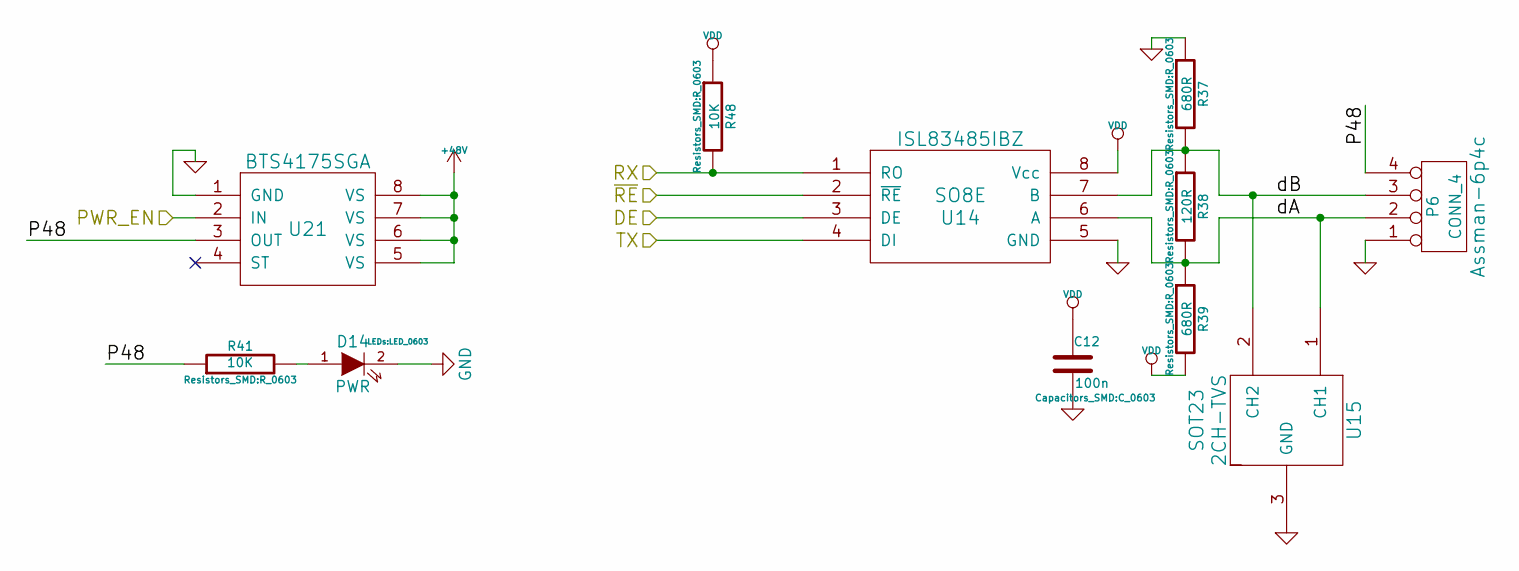
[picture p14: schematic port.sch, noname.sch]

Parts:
C7: 100n; C_0603
D4: PWR; LED_0603
P1: CONN_4; Assman-6p4c
R7, R9: 680R; R_0603
R8: 120R; R_0603
R11, R43: 10K; R_0603
U4: ISL83485IBZ; SO8E
U5: 2CH-TVS; SOT23
U16: BTS4175SGA; SOIC-8-N

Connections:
+48V: U16.5 (VS), U16.6 (VS), U16.7 (VS), U16.8 (VS); also elsewhere on the board
/DE1: U4.3 (DE); also elsewhere on the board
/PWR1: U16.2 (IN); also elsewhere on the board
/Port1/P48: P1.4, R11.1, U16.3 (OUT)
/Port1/dA: P1.2, R8.2, R9.1, U4.6 (A), U5.1 (CH1)
/Port1/dB: P1.3, R7.2, R8.1, U4.7 (B), U5.2 (CH2)
/RE1: U4.2 (~RE); also elsewhere on the board
/RX1: R43.2, U4.1 (RO); also elsewhere on the board
/TX: U4.4 (DI); also elsewhere on the board
GND: C7.2, D4.2 (K), P1.1, R7.1, U4.5 (GND), U5.3 (GND), U16.1 (GND); also elsewhere on the board
unnamed: D4.1 (A), R11.2

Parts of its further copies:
C8, C9, C10, C11, C12: 100n; C_0603
D6, D8, D10, D12, D14: PWR; LED_0603
P2, P3, P4, P5, P6: CONN_4; Assman-6p4c
R13, R15, R19, R21, R25, R27, R31, R33, R37, R39: 680R; R_0603
R14, R20, R26, R32, R38: 120R; R_0603
R17, R23, R29, R35, R41, R44, R45, R46, R47, R48: 10K; R_0603
U6, U8, U10, U12, U14: ISL83485IBZ; SO8E
U7, U9, U11, U13, U15: 2CH-TVS; SOT23
U17, U18, U19, U20, U21: BTS4175SGA; SOIC-8-N

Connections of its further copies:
+48V: U17.5 (VS), U17.6 (VS), U17.7 (VS), U17.8 (VS), U18.5 (VS), U18.6 (VS), U18.7 (VS), U18.8 (VS), U19.5 (VS), U19.6 (VS), U19.7 (VS), U19.8 (VS), U20.5 (VS), U20.6 (VS), U20.7 (VS), U20.8 (VS), U21.5 (VS), U21.6 (VS), U21.7 (VS), U21.8 (VS); also elsewhere on the board
/DE2: U6.3 (DE); also elsewhere on the board
/DE3: U8.3 (DE); also elsewhere on the board
/DE4: U10.3 (DE); also elsewhere on the board
/DE5: U12.3 (DE); also elsewhere on the board
/DE6: U14.3 (DE); also elsewhere on the board
/PWR2: U17.2 (IN); also elsewhere on the board
/PWR3: U18.2 (IN); also elsewhere on the board
/PWR4: U19.2 (IN); also elsewhere on the board
/PWR5: U20.2 (IN); also elsewhere on the board
/PWR6: U21.2 (IN); also elsewhere on the board
/Port2/P48: P2.4, R17.1, U17.3 (OUT)
/Port2/dA: P2.2, R14.2, R15.1, U6.6 (A), U7.1 (CH1)
/Port2/dB: P2.3, R13.2, R14.1, U6.7 (B), U7.2 (CH2)
/Port3/P48: P3.4, R23.1, U18.3 (OUT)
/Port3/dA: P3.2, R20.2, R21.1, U8.6 (A), U9.1 (CH1)
/Port3/dB: P3.3, R19.2, R20.1, U8.7 (B), U9.2 (CH2)
/Port4/P48: P4.4, R29.1, U19.3 (OUT)
/Port4/dA: P4.2, R26.2, R27.1, U10.6 (A), U11.1 (CH1)
/Port4/dB: P4.3, R25.2, R26.1, U10.7 (B), U11.2 (CH2)
/Port5/P48: P5.4, R35.1, U20.3 (OUT)
/Port5/dA: P5.2, R32.2, R33.1, U12.6 (A), U13.1 (CH1)
/Port5/dB: P5.3, R31.2, R32.1, U12.7 (B), U13.2 (CH2)
/Port6/P48: P6.4, R41.1, U21.3 (OUT)
/Port6/dA: P6.2, R38.2, R39.1, U14.6 (A), U15.1 (CH1)
/Port6/dB: P6.3, R37.2, R38.1, U14.7 (B), U15.2 (CH2)
/RE2: U6.2 (~RE); also elsewhere on the board
/RE3: U8.2 (~RE); also elsewhere on the board
/RE4: U10.2 (~RE); also elsewhere on the board
/RE5: U12.2 (~RE); also elsewhere on the board
/RE6: U14.2 (~RE); also elsewhere on the board
/RX2: R44.2, U6.1 (RO); also elsewhere on the board
/RX3: R45.2, U8.1 (RO); also elsewhere on the board
/RX4: R46.2, U10.1 (RO); also elsewhere on the board
/RX5: R47.2, U12.1 (RO); also elsewhere on the board
/RX6: R48.2, U14.1 (RO); also elsewhere on the board
/TX: U6.4 (DI), U8.4 (DI), U10.4 (DI), U12.4 (DI), U14.4 (DI); also elsewhere on the board
GND: C8.2, C9.2, C10.2, C11.2, C12.2, D6.2 (K), D8.2 (K), D10.2 (K), D12.2 (K), D14.2 (K), P2.1, P3.1, P4.1, P5.1, P6.1, R13.1, R19.1, R25.1, R31.1, R37.1, U6.5 (GND), U7.3 (GND), U8.5 (GND), U9.3 (GND), U10.5 (GND), U11.3 (GND), U12.5 (GND), U13.3 (GND), U14.5 (GND), U15.3 (GND), U17.1 (GND), U18.1 (GND), U19.1 (GND), U20.1 (GND), U21.1 (GND); also elsewhere on the board
unnamed: D6.1 (A), R17.2
unnamed: D8.1 (A), R23.2
unnamed: D10.1 (A), R29.2
unnamed: D12.1 (A), R35.2
unnamed: D14.1 (A), R41.2

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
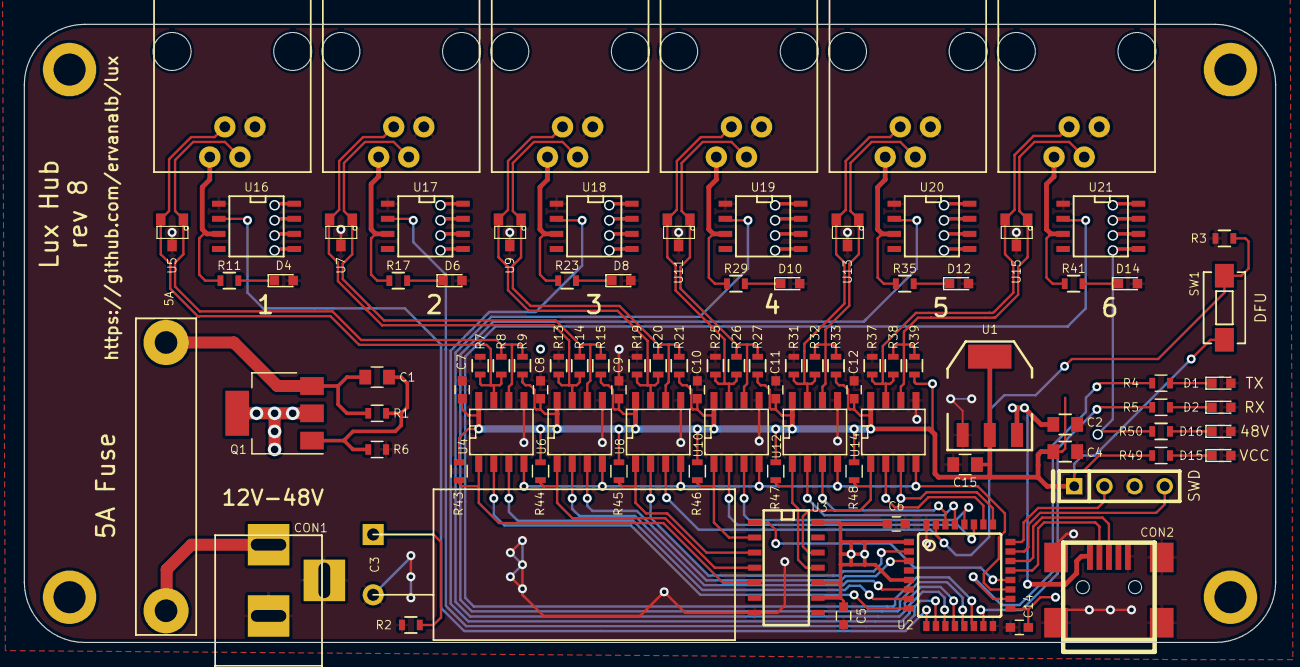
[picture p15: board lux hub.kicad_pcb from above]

Board: 4 copper layers, 105.4 x 52.1 mm, 95 parts (0 on the bottom side), 67 nets.

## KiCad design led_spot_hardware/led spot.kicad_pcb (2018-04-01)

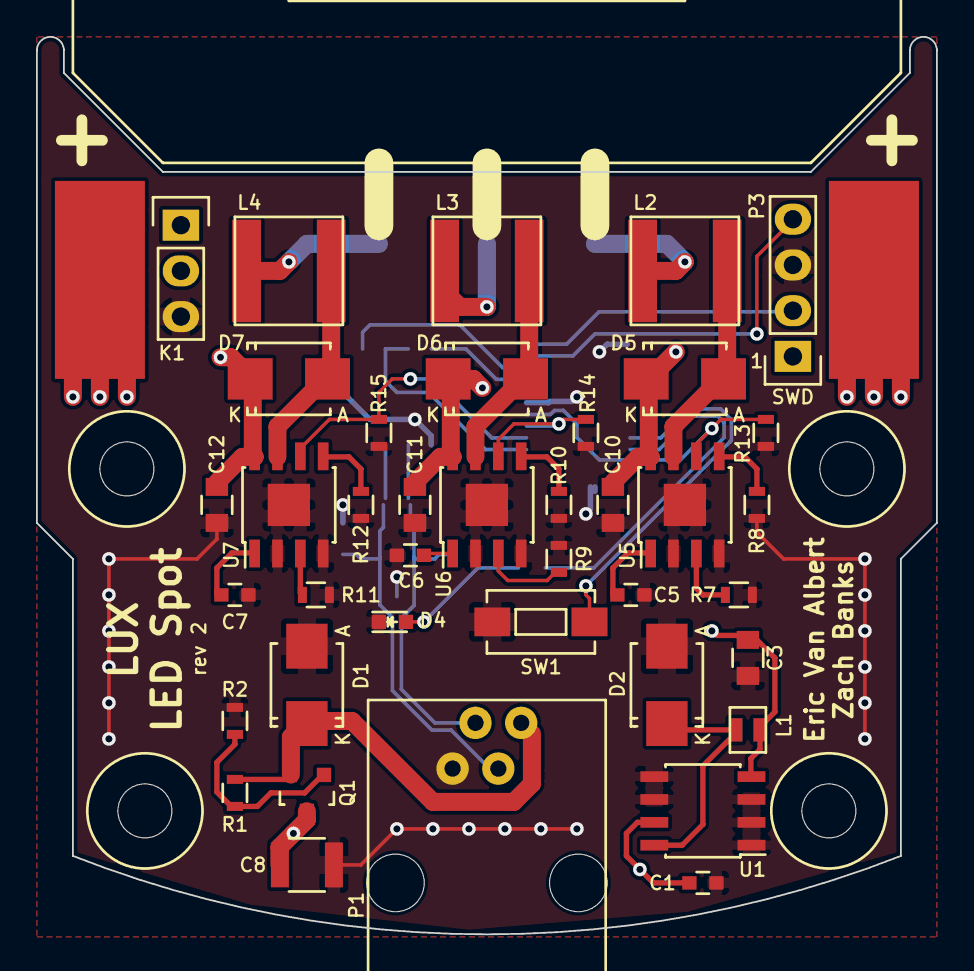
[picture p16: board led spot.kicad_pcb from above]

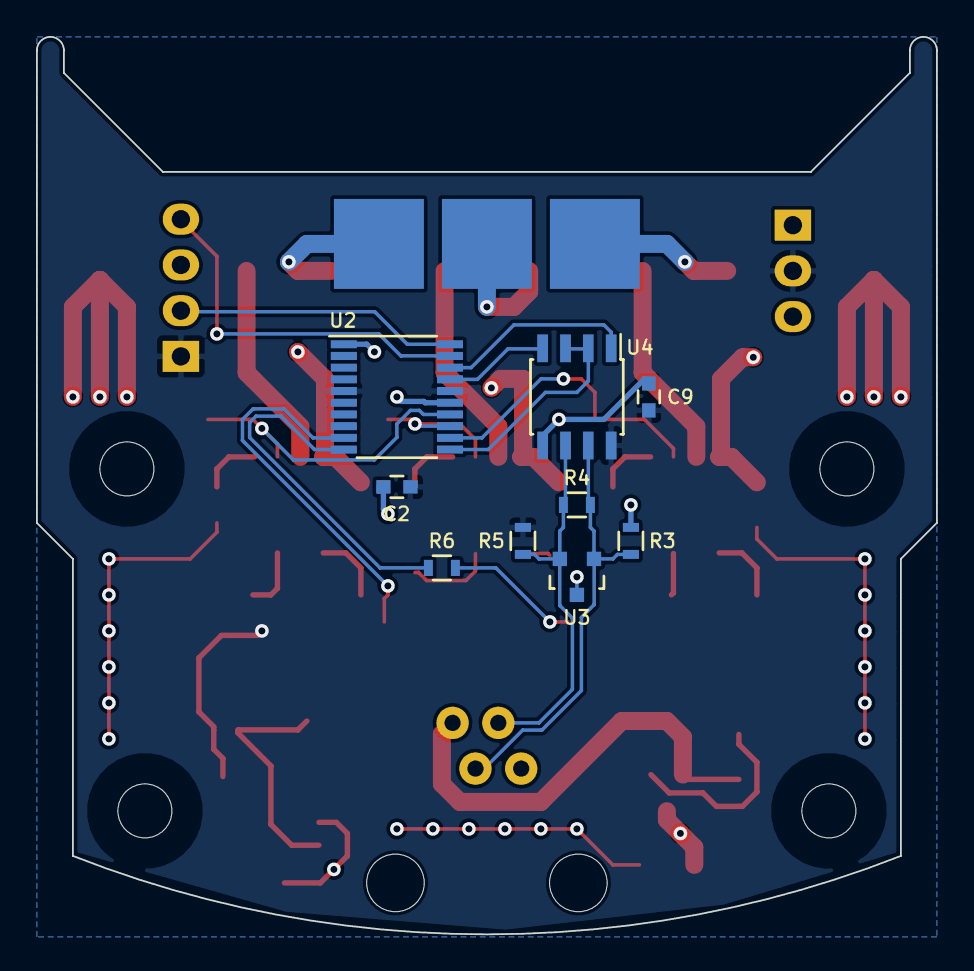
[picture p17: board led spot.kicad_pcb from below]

Board: 4 copper layers, 50.0 x 49.9 mm, 53 parts (9 on the bottom side), 31 nets.

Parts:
C1, C2, C9: 100n; C_0603
C3: 4u7; C_0805
C5, C6, C7: 1u; C_0603
C8: 2u2; C_1210
C10, C11, C12: 100n; C_0805
D1: 1SMB58AT3G; SMB_Standard
D2, D5, D6, D7: STPS1H100U; SMB_Standard
D4: USR; LED_0603
HOLE: VAL**; HOLE
HOLE#2, HOLE#3, HOLE#4: VAL**; HOLE
K1: PWR; Pin_Header_Straight_1x03
L1: 22u; VLF-M
L2, L3, L4: 100u; NRS6028T101MMGJ
P1: mod_jack_in; Assman-6p4c
P2: LED; CHINESE-LARGE-LED
P3: SWD; Pin_Header_Straight_1x04
Q1: FDN5618P; SOT-23
R1, R8, R10, R12: 22K; R_0603
R2: 47K; R_0603
R3, R5: 680R; R_0603
R4: 120R; R_0603
R6: 220R; R_0603
R7, R9, R11: 3K3; R_0603
R13, R14, R15: 1K; R_0603
SW1: SW_Push; SW_SPST_EVQPE1
U1: LM2594-HV; SOIC-8_3.9x4.9mm_Pitch1.27mm
U2: STM32F030-20; TSSOP-20_4.4x6.5mm_Pitch0.65mm
U3: 2CH-TVS; SOT-23
U4: ISL83485IBZ; SOIC-8_3.9x4.9mm_Pitch1.27mm
U5, U6, U7: TPS92511; SOIC-8-1EP_3.9x4.9mm_Pitch1.27mm

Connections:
+48V: C1.1, C8.1, C10.1, C11.1, C12.1, D5.1, D6.1, D7.1, K1.1, P2.1, Q1.3, U1.7, U5.8, U6.8, U7.8
/DE: U2.11, U4.2, U4.3
/PWM_B: R15.1, U2.12, U7.6
/PWM_G: R14.1, U2.13, U6.6
/PWM_R: R13.1, U2.14, U5.6
/RX: U2.18, U4.1
/SWCLK: P3.2, U2.20
/SWDIO: P3.4, U2.19
/TX: U2.17, U4.4
/USR_BUTTON: SW1.1, U2.9
/USR_LED: R6.1, U2.10
GND: C1.2, C2.2, C3.2, C5.2, C6.2, C7.2, C8.2, C9.2, C10.2, C11.2, C12.2, D1.2, D2.2, D4.1, K1.3, P1.1, P3.3, R2.2, R3.1, R7.1, R8.1, R9.1, R10.1, R11.1, R12.1, R13.2, R14.2, R15.2, SW1.2, U1.1, U1.2, U1.3, U1.5, U1.6, U2.1, U2.15, U3.3, U4.5, U5.2, U5.4, U5.9, U6.2, U6.4, U6.9, U7.2, U7.4, U7.9
unnamed: C5.1, U5.1
unnamed: C6.1, U6.1
unnamed: C7.1, U7.1
unnamed: D1.1, P1.4, Q1.2, R1.1
unnamed: D2.1, L1.1, U1.8
unnamed: D4.2, R6.2
unnamed: D5.2, L2.1, U5.7
unnamed: D6.2, L3.1, U6.7
unnamed: D7.2, L4.1, U7.7
unnamed: P1.2, R4.2, R5.1, U3.2, U4.6
unnamed: P1.3, R3.2, R4.1, U3.1, U4.7
unnamed: Q1.1, R1.2, R2.1
unnamed: R7.2, U5.3
unnamed: R8.2, U5.5
unnamed: R9.2, U6.3
unnamed: R10.2, U6.5
unnamed: R11.2, U7.3
unnamed: R12.2, U7.5
VCC: C2.1, C3.1, C9.1, K1.2, L1.2, P3.1, R5.2, U1.4, U2.5, U2.16, U4.8

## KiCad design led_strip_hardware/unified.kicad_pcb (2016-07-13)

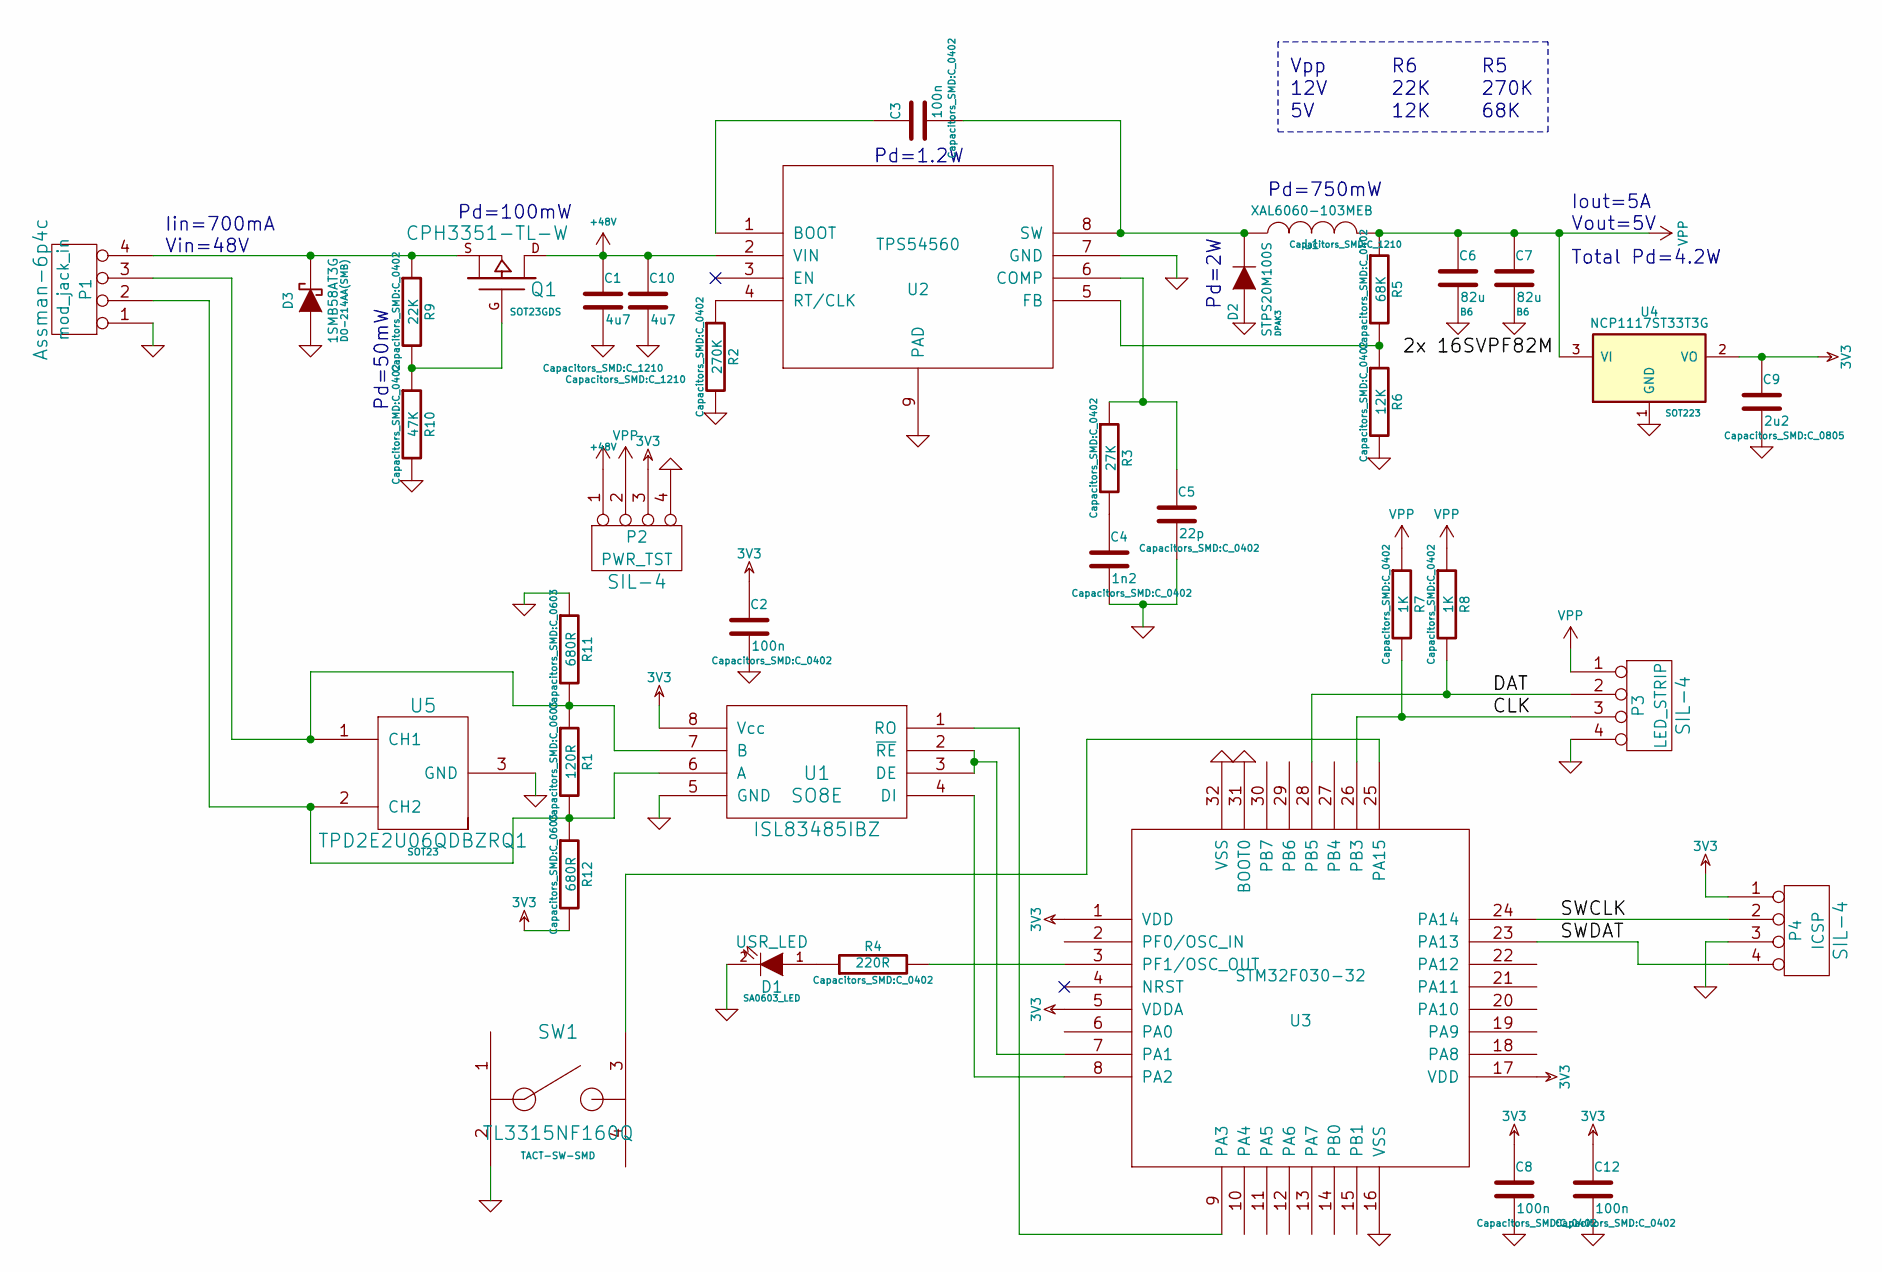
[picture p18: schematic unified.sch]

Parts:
C1, C10: 4u7; C_1210; Part C3225X7S2A475M200AB
C2, C3, C8, C12: 100n; C_0402
C4: 1n2; C_0402
C5: 22p; C_0402
C6, C7: 82u; B6; Part 16SVPF82M
C9: 2u2; C_0805
D1: USR_LED; SA0603_LED
D2: STPS20M100S; DPAK3
D3: 1SMB58AT3G; DO-214AA(SMB)
L1: XAL6060-103MEB; C_1210
P1: mod_jack_in; Assman-6p4c
P2: PWR_TST; SIL-4
P3: LED_STRIP; SIL-4
P4: ICSP; SIL-4
Q1: CPH3351-TL-W; SOT23GDS
R1: 120R; C_0603
R2: 270K; C_0402
R3: 27K; C_0402
R4: 220R; C_0402
R5: 68K; C_0402
R6: 12K; C_0402
R7, R8: 1K; C_0402
R9: 22K; C_0402
R10: 47K; C_0402
R11, R12: 680R; C_0603
SW1: TL3315NF160Q; TACT-SW-SMD
U1: ISL83485IBZ; SO8E
U2: TPS54560; SO8_WITH_EP
U3: STM32F030-32; LQFP32
U4: NCP1117ST33T3G; SOT223
U5: TPD2E2U06QDBZRQ1; SOT23

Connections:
3V3: C2.1, C8.1, C9.1, C12.1, P2.3, P4.1, R12.2, U1.8 (Vcc), U3.1 (VDD), U3.5 (VDDA), U3.17 (VDD), U4.2 (VO); also elsewhere on the board
+48V: C1.1, C10.1, P2.1, Q1.D, U2.2 (VIN)
/CLK: P3.3, R7.2, U3.26 (PB3)
/DAT: P3.2, R8.2, U3.28 (PB5)
/SWCLK: P4.2, U3.24 (PA14)
/SWDAT: P4.4, U3.23 (PA13)
GND: C1.2, C2.2, C4.2, C5.2, C6.2, C7.2, C8.2, C9.2, C10.2, C12.2, D1.2 (K), D2.1 (A), D3.1 (A), P1.1, P2.4, P3.4, P4.3, R2.2, R6.2, R10.2, R11.1, SW1.2, U1.5 (GND), U2.7 (GND), U2.9 (PAD), U3.16 (VSS), U3.31 (BOOT0), U3.32 (VSS), U4.1 (GND), U5.3 (GND); also elsewhere on the board
unnamed: C3.1, U2.1 (BOOT)
unnamed: C3.2, D2.2 (K), L1.1, U2.8 (SW)
unnamed: C4.1, R3.2
unnamed: C5.1, R3.1, U2.6 (COMP)
unnamed: D1.1 (A), R4.1
unnamed: D3.2 (K), P1.4, Q1.S, R9.1
unnamed: P1.2, R1.2, R12.1, U1.6 (A), U5.2 (CH2)
unnamed: P1.3, R1.1, R11.2, U1.7 (B), U5.1 (CH1)
unnamed: Q1.G, R9.2, R10.1
unnamed: R2.1, U2.4 (RT/CLK)
unnamed: R4.2, U3.3 (PF1/OSC_OUT)
unnamed: R5.2, R6.1, U2.5 (FB)
unnamed: SW1.3, U3.25 (PA15)
unnamed: U1.1 (RO), U3.9 (PA3)
unnamed: U1.2 (~RE), U1.3 (DE), U3.7 (PA1)
unnamed: U1.4 (DI), U3.8 (PA2)
VPP: C6.1, C7.1, L1.2, P2.2, P3.1, R5.1, R7.1, R8.1, U4.3 (VI)

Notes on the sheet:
Vpp
12V
68K
12K
22K
270K
Pd=100mW
Pd=50mW
Pd=750mW
Iin=700mA Vin=48V
Iout=5A Vout=5V
Pd=1.2W
Pd=2W
Total Pd=4.2W

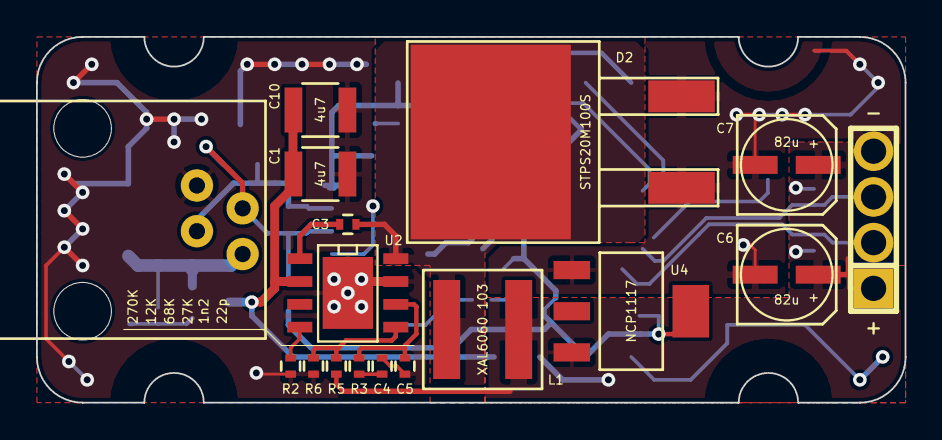
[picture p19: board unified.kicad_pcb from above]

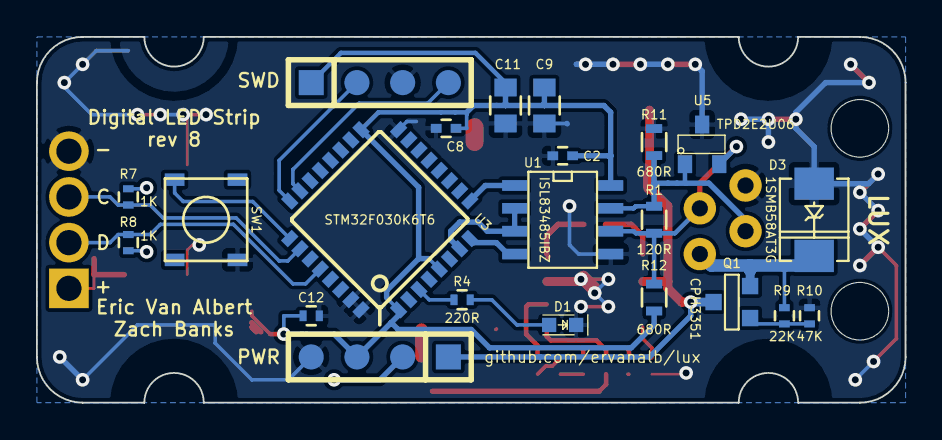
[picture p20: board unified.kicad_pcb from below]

Board: 4 copper layers, 48.3 x 20.3 mm, 39 parts (22 on the bottom side), 24 nets.

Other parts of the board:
C11: 2u2; C_0805

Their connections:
3V3: C11.1; also elsewhere on the board
GND: C11.2; also elsewhere on the board

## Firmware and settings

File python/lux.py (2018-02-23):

import struct
import binascii
import serial

class TimeoutError(Exception):
    pass

class DeviceTypeError(Exception):
    pass

class DecodeError(Exception):
    pass

class CommandError(Exception):
    pass

class Bus(object):
    MULTICAST = 0xFFFFFFFF

    @staticmethod
    def cobs_encode(data):
        output = b''
        data += b'\0'
        ptr = 0
        while ptr < len(data):
            next_zero = data.index(b'\0', ptr)
            if next_zero - ptr >= 254:
                output += b'\xFF' + data[ptr:ptr+254]
                ptr += 254
            else:
                output += bytearray((next_zero - ptr + 1,)) + data[ptr:next_zero]
                ptr = next_zero + 1
        return output

    @staticmethod
    def cobs_decode(data):
        output = b''
        ptr = 0
        while ptr < len(data):
            ctr = data[ptr]
            if ptr + ctr > len(data):
                raise DecodeError("COBS decoding failed", repr(data))
            output += data[ptr + 1:ptr + ctr]
            if ctr < 255:
                output += b'\0'
            ptr += ctr
        if ptr != len(data):
            raise DecodeError("COBS decoding failed", repr(data))
        return output[0:-1]

    @classmethod
    def frame(cls, destination, command, data, index=0):
        packet = struct.pack('<IBB', destination, command, index) + data
        cs = binascii.crc32(packet) & ((1 << 32) - 1)
        cs_bytes = struct.pack('<I', cs)
        return cls.cobs_encode(packet + cs_bytes), cs_bytes

    @classmethod
    def unframe(cls, packet):
        packet = cls.cobs_decode(packet)
        cs=binascii.crc32(packet) & ((1<<32)-1)
        if cs != 0x2144DF1C:
            raise DecodeError("BAD CRC: "+hex(cs), repr(packet))
        return struct.unpack('<IBB',packet[0:6]) + (packet[6:-4], packet[-4:])

    def __init__(self, device):
        self.s = None
        self.dev = device
        self.rx = b''
        self.timeout = 0.5

    def __enter__(self):
        self.open()
        return self

    def __exit__(self, type, value, traceback):
        self.close()

    def open(self):
        self.s = serial.Serial(self.dev, 3000000, timeout = self.timeout, writeTimeout = self.timeout, xonxoff = False)

    def close(self):
        self.s.close()
        self.s = None

    def lowlevel_write(self, data):
        data += b'\0'
        try:
            self.s.write(data)
        except serial.SerialTimeoutException as e:
            raise TimeoutError("lux write timed out") # from e

    def lowlevel_read(self):
        while True:
            while b'\0' not in self.rx:
                r = self.s.read()
                if len(r) == 0:
                    print("timeout")
                    raise TimeoutError("lux read timed out")
                self.rx += r 
            while b'\0' in self.rx:
                frame, _null, self.rx = self.rx.partition(b'\0')
                return bytearray(frame)

    def read(self):
        while True:
            try:
                return self.unframe(self.lowlevel_read())
            except DecodeError:
                pass

    def clear_rx(self):
        self.rx = b''
        t = self.s.timeout
        try:
            self.s.timeout = 0
            self.s.read()
        finally:
            self.s.timeout = t
   
    def write(self, destination, command, data, index=0):
        self.clear_rx()
        packet, crc = self.frame(destination, command, data, index=index)
        self.lowlevel_write(packet)
        return crc

    def ping(self, destination):
        self.write(destination, 0, b'', 0)
        return self.read()

class Device(object):
    # General Lux Commands
    CMD_GET_ID = 0x00
    CMD_GET_DESCRIPTOR = 0x01
    CMD_RESET = 0x02
    #CMD_BOOTLOADER = 0x02

    # Configuration commands
    CMD_COMMIT_CONFIG = 0x10

    CMD_GET_ADDR = 0x11
    CMD_SET_ADDR = 0x12

    CMD_GET_PKTCNT = 0x13
    CMD_RESET_PKTCNT = 0x14

    def __init__(self, bus, address):
        self.bus = bus
        self.address = address

    def command(self, command, data, index=0, retry=5, get_crc=False):
        for r in range(retry):
            try:
                crc = self.write(command=command, data=data, index=index)
                rx_destination, rx_command, rx_index, rx_data, rx_crc = self.bus.read()
                if rx_destination != 0:
                    raise DecodeError
                if rx_command != command or rx_index != index:
                    raise DecodeError
                return rx_data if not get_crc else (rx_data, crc)
            except (TimeoutError, DecodeError):
                if r == retry - 1:
                    raise

    def ack_command(self, *args, **kwargs):
        kwargs["get_crc"] = True
        response, crc = self.command(*args, **kwargs)
        if response[1:5] == crc:
            rc = response[0]
            if rc == 0:
                return # Success
            else:
                raise CommandError(rc)
        else:
            raise DecodeError

    def write(self, *args, **kwargs):
        return self.bus.write(self.address, *args, **kwargs)

    def get_id(self, *args, **kwargs):
        return self.command(self.CMD_GET_ID, b'', *args, **kwargs)

    def reset(self, flags=0):
        self.write(self.CMD_RESET, bytearray((flags,)))

    def bootloader(self):
        """ Cause device to jump to bootloader """
        self.reset(flags=0x01)

    def set_address(self, multicast_base = Bus.MULTICAST, multicast_mask = 0, unicast = None, *args, **kwargs):
        if unicast is None:
            unicast = []
        unicast += [Bus.MULTICAST] * (16 - len(unicast))
        self.ack_command(self.CMD_SET_ADDR, struct.pack("18I", multicast_base, multicast_mask, *unicast), *args, **kwargs)

    def get_address(self, *args, **kwargs):
        r = self.command(self.CMD_GET_ADDR, b'', *args, **kwargs)
        a = struct.unpack("18I", r)
        return a[0], a[1], a[2:]

    def write_config(self, *args, **kwargs):
        self.ack_command(self.CMD_COMMIT_CONFIG, b'', *args, **kwargs)

    def get_packet_stats(self, *args, **kwargs):
        r = self.command(self.CMD_GET_PKTCNT, b'', *args, **kwargs)
        metrics = struct.unpack("IIIII", r)
        desc = (
                "good",
                "malformed",
                "overrun",
                "checksum",
                "interrupted"
               )
        return dict(zip(desc, metrics))

    def reset_packet_stats(self, *args, **kwargs):
        self.ack_command(self.CMD_RESET_PKTCNT, b'', *args, **kwargs)

class LEDStrip(Device):
    # Strip-specific configuration
    CMD_SET_LENGTH = 0x9C
    CMD_GET_LENGTH = 0x9D

    # Strip-specific commands
    CMD_FRAME = 0x92
    CMD_FRAME_ACK = 0x93

    CMD_SET_LED = 0x96
    CMD_GET_BUTTON = 0x97

    def __init__(self, *args, **kwargs):
        super(LEDStrip, self).__init__(*args, **kwargs)
        self.type_id = str(self.get_id())
        if self.type_id not in {'WS2811 LED Strip', 'LPD6803 LED Strip'}:
            raise DeviceTypeError(self.type_id)
        self.get_length()

    def get_length(self):
        r = self.command(self.CMD_GET_LENGTH, b'')
        self.length = struct.unpack("H", r)[0]
        return self.length

    def set_length(self, length):
        self.ack_command(self.CMD_SET_LENGTH, struct.pack('H', length))

    def send_solid_frame(self, pixel, *args, **kwargs):
        self.send_frame([pixel] * self.length, *args, **kwargs)

    def send_frame(self, pixels, ack = False):
        if len(pixels) != self.length:
            raise RuntimeError("Expected {0} pixels, got {1}".format(self.length, len(pixels)))
        data = bytearray()
        for r,g,b in pixels:
            data += bytearray((int(r), int(g), int(b)))

        if ack:
            self.command(self.CMD_FRAME_ACK, data)
        else:
            self.write(self.CMD_FRAME, data)

    def set_led(self, state):
        self.ack_command(self.CMD_SET_LED, struct.pack('?', state))

    def get_button(self):
        r = self.command(self.CMD_GET_BUTTON)
        return struct.unpack('?', r)[0]

class LEDSpot(Device):
    # Spot-specific commands
    CMD_COLOR = b'\x90'
    CMD_COLOR_ACK = b'\x91'
    CMD_SET_LED = b'\x92'

    def __init__(self, *args, **kwargs):
        super(LEDSpot, self).__init__(*args, **kwargs)
        self.type_id = self.get_id()
        if self.type_id != b'LED Spot':
            raise DeviceTypeError(self.type_id)

    def set_color(self, color, ack = False, *args, **kwargs):
        (r, g, b) = color
        data = bytes((int(r), int(g), int(b)))
        if ack:
            self.command(self.CMD_COLOR_ACK + data)
        else:
            self.write(self.CMD_COLOR + data)

    def set_led(self, state, *args, **kwargs):
        self.ack_command(self.CMD_SET_LED + struct.pack('?', state), *args, **kwargs)

if __name__ == '__main__':
    import time
    tail = 30

    with Bus('/dev/ttyACM0') as bus:
        print(bus.ping(0xFFFFFFFF))
        spot = LEDSpot(bus, 0xFFFFFFFF)
        spot.set_color((0, 0, 0))

        #strip.set_length(140)
        #strip.set_address(unicast=[2])
        #print(strip.get_address())
        #strip.write_config()
        #l = strip.get_length()

        #pos = 0
        #while True:
        #    frame = [(0,0,0)] * l
        #    for i in range(tail+1):
        #        v = 255 * i / tail
        #        frame[(pos + i) % l] = (v, v, v)

        #    strip.send_frame(frame)
        #    time.sleep(0.01)

        #    pos = (pos + 1) % l

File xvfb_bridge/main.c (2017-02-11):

#include <X11/Xos.h>
#include <X11/Xlib.h>
#include <X11/Xutil.h>
#include <X11/cursorfont.h>
#include <X11/extensions/XShm.h>
#include <stdlib.h>
#include <stdio.h>
#include <sys/shm.h>
#include <time.h>

#include "linux/lux.h"
#include "log.h"

enum loglevel loglevel = LOGLEVEL_INFO;

Window Select_Window(Display * dpy, int screen) {
  int status;
  Cursor cursor;
  XEvent event;
  Window target_win = None, root = RootWindow(dpy,screen);
  int buttons = 0;

  /* Make the target cursor */
  cursor = XCreateFontCursor(dpy, XC_crosshair);

  /* Grab the pointer using target cursor, letting it room all over */
  status = XGrabPointer(dpy, root, False,
			ButtonPressMask|ButtonReleaseMask, GrabModeSync,
			GrabModeAsync, root, cursor, CurrentTime);
  if (status != GrabSuccess) FAIL("Can't grab the mouse.");

  /* Let the user select a window... */
  while ((target_win == None) || (buttons != 0)) {
    /* allow one more event */
    XAllowEvents(dpy, SyncPointer, CurrentTime);
    XWindowEvent(dpy, root, ButtonPressMask|ButtonReleaseMask, &event);
    switch (event.type) {
    case ButtonPress:
      if (target_win == None) {
	target_win = event.xbutton.subwindow; /* window selected */
	if (target_win == None) target_win = root;
      }
      buttons++;
      break;
    case ButtonRelease:
      if (buttons > 0) /* there may have been some down before we started */
	buttons--;
       break;
    }
  } 

  XUngrabPointer(dpy, CurrentTime);      /* Done with pointer */

  return(target_win);
}

Window Window_With_Name(Display * dpy, Window top, char * name) {
	Window *children, dummy;
	unsigned int nchildren;
	int i;
	Window w=0;
	char *window_name;

	if (XFetchName(dpy, top, &window_name) && !strcmp(window_name, name))
	  return(top);

	if (!XQueryTree(dpy, top, &dummy, &dummy, &children, &nchildren))
	  return(0);

	for (i=0; i<(int)nchildren; i++) {
		w = Window_With_Name(dpy, children[i], name);
		if (w)
		  break;
	}
	if (children) XFree ((char *)children);
	return(w);
}

struct grabber {
    // X11 things
    Display * display;
    int screen;
    Window window;
    XWindowAttributes window_attrs;
    XImage *image;
    XShmSegmentInfo shminfo;

    // Per-pixel
    size_t size;
    double * xs;
    double * ys;
    XColor * colors;
};

int grabber_init(struct grabber * grabber, size_t size) {
    memset(grabber, 0, sizeof *grabber);

    grabber->size = size;
    grabber->xs = calloc(sizeof *grabber->xs, size);
    ASSERT(grabber->xs != NULL);
    grabber->ys = calloc(sizeof *grabber->ys, size);
    ASSERT(grabber->ys != NULL);
    grabber->colors = calloc(sizeof *grabber->colors, size);
    ASSERT(grabber->colors != NULL);

    grabber->display = XOpenDisplay(NULL);
    ASSERT(grabber->display != NULL, "Unable to open display");

    grabber->screen = DefaultScreen(grabber->display);
    INFO("Select window...");
    grabber->window = Select_Window(grabber->display, grabber->screen);

    int rc = XGetWindowAttributes(grabber->display, grabber->window, &grabber->window_attrs);
    ASSERT(rc == 1, "Unable to get window attributes (%d)", rc);

    // Setup shm
    XImage *img = XShmCreateImage(
            grabber->display,
            grabber->window_attrs.visual,
            grabber->window_attrs.depth,
            ZPixmap,
            NULL,
            &grabber->shminfo,
            grabber->window_attrs.width,
            grabber->window_attrs.height);
    grabber->shminfo.shmid = shmget(IPC_PRIVATE, img->bytes_per_line * img->height, IPC_CREAT | 0777);
    ASSERT(grabber->shminfo.shmid != -1);

    grabber->shminfo.shmaddr = img->data = shmat(grabber->shminfo.shmid, 0, 0);
    grabber->shminfo.readOnly = 0;

    rc = XShmAttach(grabber->display, &grabber->shminfo);
    ASSERT(rc);

    grabber->image = img;

    return 0;
}

int grabber_grab(struct grabber * grabber) {
    //int x = 0, y = 0;
    int w = grabber->window_attrs.width, h = grabber->window_attrs.height;
    //XImage * image = XGetImage(grabber->display, grabber->window, x, y, w, h, AllPlanes, XYPixmap);
    //ASSERT(image != NULL, "Unable to capture image");
    int rc = XShmGetImage(grabber->display, grabber->window, grabber->image, 0, 0, AllPlanes);
    ASSERT(rc);
    XImage * image = grabber->image;

    memset(grabber->colors, 0, grabber->size * sizeof *grabber->colors);
    for (size_t i = 0; i < grabber->size; i++) {
        int px = w * grabber->xs[i];
        int py = h * grabber->xs[i];
        grabber->colors[i].pixel = XGetPixel(image, px, py);
    }

    rc = XQueryColors(grabber->display, grabber->window_attrs.colormap, grabber->colors, grabber->size);
    ASSERT(rc == 1, "Unable to query colors (%d)", rc);

    //XFree(image);

    return 0;
}

int grabber_grabsparse(struct grabber * grabber) {
    int w = grabber->window_attrs.width, h = grabber->window_attrs.height;
    memset(grabber->colors, 0, grabber->size * sizeof *grabber->colors);

    XImage * image = XGetImage(grabber->display, grabber->window, 0, 0, 1, 1, AllPlanes, XYPixmap);
    ASSERT(image != NULL, "Unable to capture image");

    for (size_t i = 0; i < grabber->size; i++) {
        int px = w * grabber->xs[i];
        int py = h * grabber->xs[i];

        void * ri = XGetSubImage(grabber->display, grabber->window, px, py, 1, 1, AllPlanes, XYPixmap, image, 0, 0);
        ASSERT(ri != NULL);

        grabber->colors[i].pixel = XGetPixel(image, 0, 0);

    }
    XFree(image);

    int rc = XQueryColors(grabber->display, grabber->window_attrs.colormap, grabber->colors, grabber->size);
    ASSERT(rc == 1, "Unable to query colors (%d)", rc);

    return 0;
}
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

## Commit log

2015-02-19 fixing small bug in COBS implementation
    [lux.c]
2015-02-26 speeding up SPI and doing some speed tests
2015-02-27 broken; trying to implement DMA interrupts
    [ws2811_strip.c]
2015-03-02 first pass at DMA for transferring to LED strips
2015-03-05 adding python directory and perlin noise script
    [lux.py]
2015-03-05 fixing ws2811 bug and adding some python
    [lux.py, noise.py, ws2811_strip.c]
2015-03-05 changing parameters of noise demo
    [noise.py]
2015-03-05 fixing bug in noise.py and improving nosylights
    [noise.py, noisylights.py]
2015-03-22 Adding more commands to LED boards; lux python rx
    LED Boards support:
    - Setting on-board LED state
    - Reading on-board button state
    - Configuring (volatile) unicast/multicast addresses
    - Reading 'id' string ("WS2811 LED Strip")
2015-03-22 adding some bootloader assembly
2015-03-23 Update README.md
    de-facto standards
2015-03-23 Refactoring python; fixed r/g ws2811
    [lux.py, luxflash.py, main.c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]
2015-08-27 SO UNTESTED DIDN'T EVEN COMPILE IT BUT ITS ALL THERE (maybe)
    [hal.c]
2015-09-14 make lux hub add some space between chunks of data, minor bugfixes all around, everything seems to work
    [hal.c, lux.py]
2015-09-15 flasher doesn't quite work
    [hal.c, lux.py, luxflash.py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]
2015-09-21 switch back to pyserial
2015-09-23 fix bug in cobs encoder
    [lux.py]
2016-01-31 fix small bug in lux.py and write lux_udp.py
    [lux.py, lux_udp.py]
2016-02-07 Fix lux.py to work in both python 2.7 & 3.x
    [lux.py]
2016-04-23 Adding old lux hub (v4)
    [lux hub-B_Cu.gbl, lux hub-B_Mask.gbs, lux hub-B_SilkS.gbo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]
2016-04-27 kicad hardware files
    [bom.csv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]
2016-05-01 Progress on v7 of led_strip_hardware
    [unified.kicad_pcb, unified.sch]
2016-05-02 add led spot
2016-05-07 Progress on v7 of led_strip_hardware; some lux utilities
    [lux hub.kicad_pcb, lux hub.sch, port.sch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]
2016-05-07 fix dropped bytes by changing interrupt priorities
    [hal.c]
2016-05-22 LED hardware rev 7
    [unified.kicad_pcb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]
2016-05-22 LED strip hardware rev 7; added mask gebers & moved via
    [unified.kicad_pcb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]
2016-05-23 LED strip hardware rev 7; ready for prod?
    [unified-B.Cu.gbl, unified-B.Mask.gbs, unified-B.SilkS.gbo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]
2016-05-23 Cleaned up led strip gerber directory
    [unified-B.Cu.gbl, unified-B.Mask.gbs, unified-B.SilkS.gbo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]
2016-05-24 More 'final' touches
    [unified-B.Cu.gbl, unified-B.Mask.gbs, unified-B.SilkS.gbo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]
2016-05-24 Flipped D2; still need to fix silk bottom
    [unified-B.Cu.gbl, unified-B.Mask.gbs, unified-B.SilkS.gbo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]
2016-05-24 ship it
    [unified-B.Cu.gbl, unified-B.Mask.gbs, unified-B.SilkS.gbo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]
2016-05-29 Copper for the hub
    [lux hub.kicad_pcb, lux hub.sch, port.sch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]
2016-07-02 Hub gerbers; Reverting changes to lux API;
    [lux hub-B_Cu.gbl, lux hub-B_Mask.gbs, lux hub-B_SilkS.gbo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]
2016-07-13 LED Strip rev 8
    [lux hub-B.Cu.gbl, lux hub-B.Mask.gbs, lux hub-B.SilkS.gbo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]
2016-07-14 add BOM for assembly
    [unified-bom.csv]
2016-07-14 fix TVS part no
    [unified-bom.csv]
2017-02-11 X11 -> lux bridge prototype
    [lux hub.sch]
2017-02-18 Break out `lux_(un)frame` from liblux
2018-03-18 improvements to LED spot
    [led spot.kicad_pcb, led spot.sch, led_driver.sch]
2018-03-18 finish updating LED spot
    [led spot.kicad_pcb, led spot.sch, led_driver.sch]
2018-03-24 WIP Lux Hub v7
    * Replace PTCs with current-limiting circuit
    * Widen board and add 4x2mm mounting holes
    * TODO: Rearrange some components on the edges
    * TODO: Check silkscreen (esp. LEDs)
    [lux hub.kicad_pcb, lux hub.sch, port.sch]
2018-03-24 WIP Lux Hub v7; need to re-route 1W 2512 resistors
    [lux hub.kicad_pcb]
2018-03-24 WIP Lux Hub v7; proposed re-route
    [lux hub.kicad_pcb]
2018-03-26 Lux Hub v7 (done)
    [lux hub.kicad_pcb]
2018-04-01 rev 2 gerbers
    [led spot-B.Cu.gbl, led spot-B.Mask.gbs, led spot-B.SilkS.gbo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]
2018-04-01 Export hub gebers v7
    [lux hub-B.Cu.gbl, lux hub-B.Mask.gbs, lux hub-B.SilkS.gbo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]
2018-04-01 Fix inner copper pour
    [lux hub-B.Cu.gbl, lux hub-B.Mask.gbs, lux hub-B.SilkS.gbo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]
2018-05-12 Add thermal pad SVG for laser cutting
2018-05-16 Lux Hub v8
    [lux hub-B.Cu.gbl, lux hub-B.Mask.gbs, lux hub-B.SilkS.gbo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]
2018-05-16 Lux Hub v8 - zip w/ gerbers
2018-05-17 Add soft-start circuit to lux hub v8, update gerbers
    [lux hub-B.Cu.gbl, lux hub-B.Mask.gbs, lux hub-B.SilkS.gbo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]
2018-05-18 Fix ws2811 strip_write function
    [lpd6803_strip.c, main.c, ws2811_strip.c]
2018-06-19 'Fix' led_strip_firmware config.c flash issues, add new commands (read config, detect devices) to luxctl
    [lux.c]
